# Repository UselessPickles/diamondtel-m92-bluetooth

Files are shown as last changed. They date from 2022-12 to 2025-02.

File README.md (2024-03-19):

# DiamondTel Model 92 Bluetooth Adapter



This is an electronics/microcontroller project for adapting a DiamondTel Model 92 Portable Cellular Telephone to work as a fully functional phone by routing calls through a modern cell phone via the Bluetooth Hands-Free Profile (HFP).

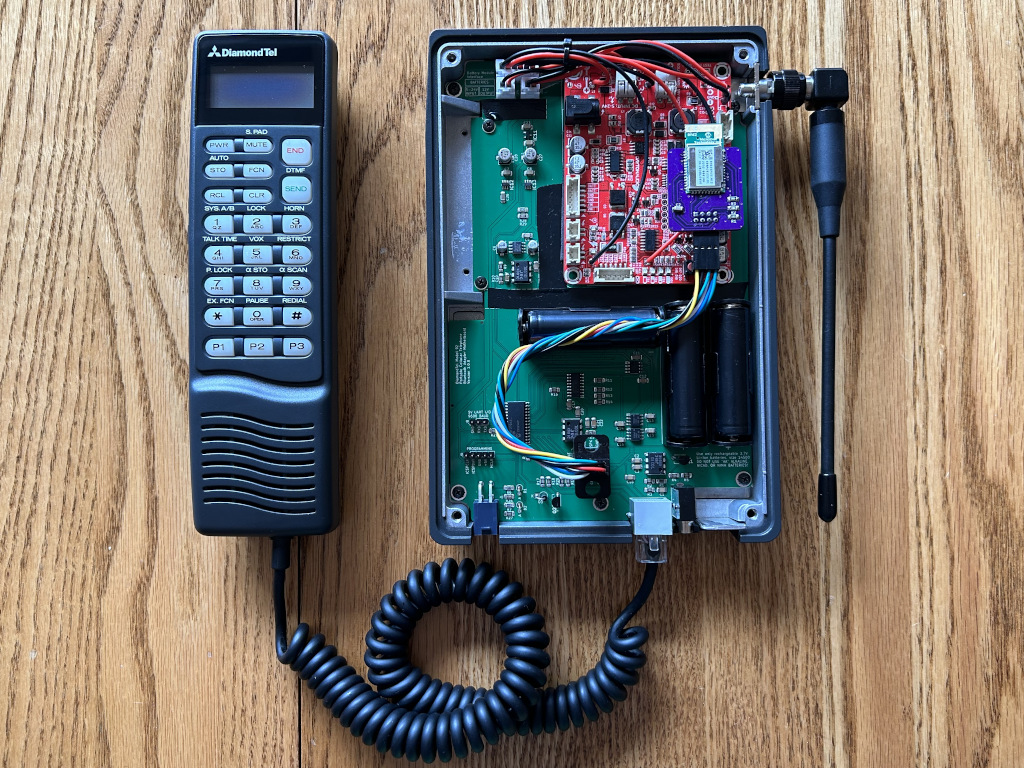
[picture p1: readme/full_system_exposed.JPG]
DiamondTel Model 92 Telephone with Bluetooth adapter electronics exposed
|

This project includes both a custom electronics circuit and custom microcontroller software.

- [DiamondTel Model 92 Bluetooth Adapter](#diamondtel-model-92-bluetooth-adapter)
  - [About This Project](#about-this-project)
    - [TL;DR (with demo videos)](#tldr-with-demo-videos)
    - [The DiamondTel Model 92 Portable Cellular Telephone](#the-diamondtel-model-92-portable-cellular-telephone)
    - [Motivation / Goals](#motivation--goals)
    - [Project Forum Thread](#project-forum-thread)
    - [Discussion](#discussion)
    - [Documentation](#documentation)
    - [Media Coverage](#media-coverage)
  - [Basic Design](#basic-design)
    - [High Level Design Summary](#high-level-design-summary)
    - [Design Pros/Cons](#design-proscons)
  - [Compatibility](#compatibility)
    - [Vintage Mobile Phone](#vintage-mobile-phone)
    - [Paired Modern Cell Phone](#paired-modern-cell-phone)
  - [About the Author](#about-the-author)  
## About This Project

### TL;DR (with demo videos)

I have an old car phone in my early 90's car. It's impossible to activate service for these old phones. I made the old car phone actually work like a real phone.

Click to view a YouTube video tour and demo of the complete car phone system with Bluetooth adapter (NOTE: This video shows an older external plug-in version):

YouTube video tour and demo of the complete car phone system with Bluetooth adapter (https://www.youtube.com/watch?v=52AuhS5Jq0Q)

Click to view a YouTube video demo and disassembly of the new internal adapter design:

YouTube video demo and disassembly of new internal adapter (https://www.youtube.com/watch?v=uEtvmijlxUE)

You can find all videos I have created about this project in [this YouTube playlist](https://www.youtube.com/playlist?list=PLOlio4FadqvQEWHDXaJHlkvHigROk-RNV).

### The DiamondTel Model 92 Portable Cellular Telephone

The DiamondTel Model 92 Portable Cellar Telephone is a hybrid transportable/mobile (mobile, as in, "car phone") manufactured by Mitsubishi in the early 1990's. 

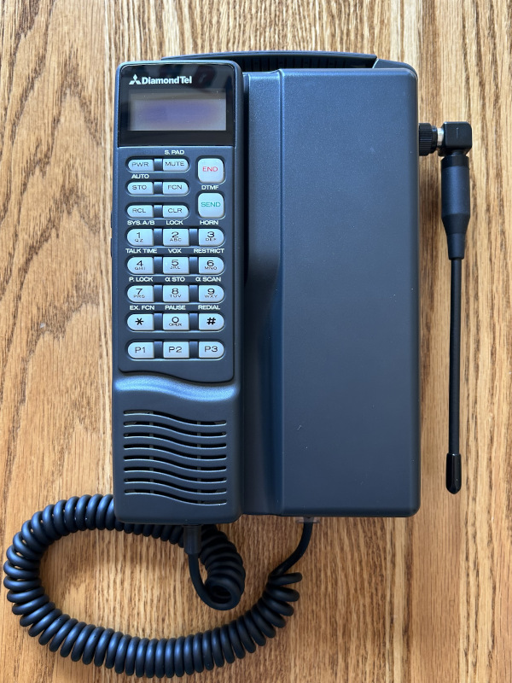
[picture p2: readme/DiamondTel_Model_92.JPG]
DiamondTel Model 92 Portable Cellular Telephone


The phone used 1G analog cellular technology ([AMPS](https://en.wikipedia.org/wiki/Advanced_Mobile_Phone_System)), which has been discontinued in the US since 2008. As such, it is impossible to activate service for this phone. 

See the contents and README in the `telephone` directory for more details.

### Motivation / Goals

I want my DiamondTel Model 92 telephone to actually work as a phone, and not just by hacking an off-the-shelf Bluetooth headset into the phone's handset. I want the complete experience of the phone to be nearly indistinguishable from how the phone was originally intended to behave:

- Incoming calls should cause the phone to ring, and I should be able to answer incoming calls as expected (press the "SEND" button or pick up the handset).
- I should be able to place outgoing calls by dialing a number on the handset then pressing "SEND".
- The handset display should work and display all relevant information just like the original phone did.
- Sounds should be accurate to the original phone (button press sounds, ringtone, status alert sounds, etc.).
- A majority of the phone's original features should be fully functional (e.g., volume controls, call timer, quick dial presets, contacts directory with names and numbers).

### Project Forum Thread

I have documented my entire journey with this project in an [Electro-Tech-Online.com forum thread](https://www.electro-tech-online.com/threads/making-a-bluetooth-adapter-for-a-car-phone-from-the-90s.162764/).

Browse this thread if you are interested in all the technical details of how I reverse-engineerd how the DiamondTel Model 92 telephone works, how I fumbled my way through the electronics/hardware (with much appreciated assistance), and various problems I had to solve.

Subscribe to this thread if you want to be notified of significant updates about this project.

### Discussion

Do you have something to ask/say about this project? You can reach out to me in [this Gitter chat room](https://gitter.im/UselessPickles/diamondtel-m92-bluetooth) or DM me on [Instagram (@uselesspickles)](https://www.instagram.com/uselesspickles/).

### Documentation

There's too much information to put in one README. Most directories of this project have a README containing relevant documentation for that portion of the project. So explore the directory structure and use the READMEs to get familiar with it.

### Media Coverage

There's been a bit of media coverage of my project. Here's some links:

- [Hackaday](https://hackaday.com/2023/04/13/custom-bluetooth-adapter-brings-1990s-car-phone-back-online/)
- [Jalopnik](https://jalopnik.com/vintage-factory-car-phone-connects-to-smartphone-1850329711)
- [CarBuzz](https://carbuzz.com/news/genius-turns-30-year-old-mitsubishi-3000gt-into-a-smartphone)
- Hagerty: Piston Slap
    - [Part 1](https://www.hagerty.com/media/advice/piston-slap/piston-slap-new-tricks-for-an-old-car-phone-part-iv/)
    - [Part 2](https://www.hagerty.com/media/advice/piston-slap/piston-slap-new-tricks-for-an-old-car-phone-part-v/)
- [Japanese Nastolgic Car](https://japanesenostalgiccar.com/mitsubishi-3000gt-car-phone-functional-with-iphone-bluetooth/)
- [Hackster.io](https://www.hackster.io/news/jeff-lau-s-open-source-bluetooth-adapter-brings-a-mitsubishi-carphone-classic-back-from-the-dead-383864868529)
- [The Drive](https://www.thedrive.com/news/clever-collector-mods-mitsubishi-3000gt-car-phone-to-work-like-an-iphone)

## Basic Design

### High Level Design Summary

This Bluetooth adapter is a complete replacement of the electronics inside the transceiver of the car phone. The handset of the car phone remains completely original and unmondified. The Bluetooth adapter pairs with a modern cell phone using the Hands-Free Profile (HFP), which enables the car phone handset to receive incoming calls and make outgoing calls through the paired modern cell phone.
    
The majority of the electronics is on the "motherboard" that installs in the metal transceiver case, and a smaller Bluetooth module "daugherboard" installs in the battery compartment of the plastic "transportable cover" so that the Bluetooth signal is not obstructed by the metal transceiver case.

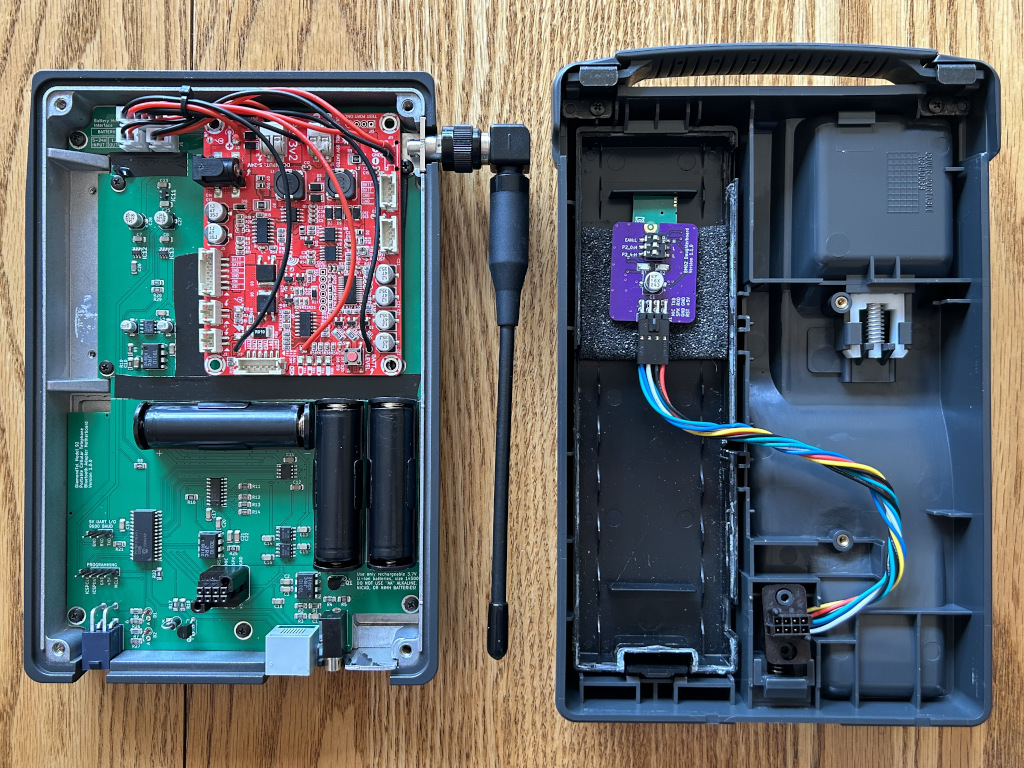
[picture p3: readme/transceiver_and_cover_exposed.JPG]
Transceiver and Transporable Cover with electronics exposed


The motherboard uses the same type of connectors as the original electronics for external power supply, handset cord, and external microphone. The connection between the mootherboard and the Bluetooth module daugherboard reuses the connectors that were originally used to connect the battery circuitry in the transportable cover to the transceiver. And finally, the Bluetooth module daughterboard can be hidden in the emptied shell of an original battery pack. The end result is that the modified car phone is practically visually indistinguishable from an original unmodified car phone, even when removing the transportable cover from the transceiver.

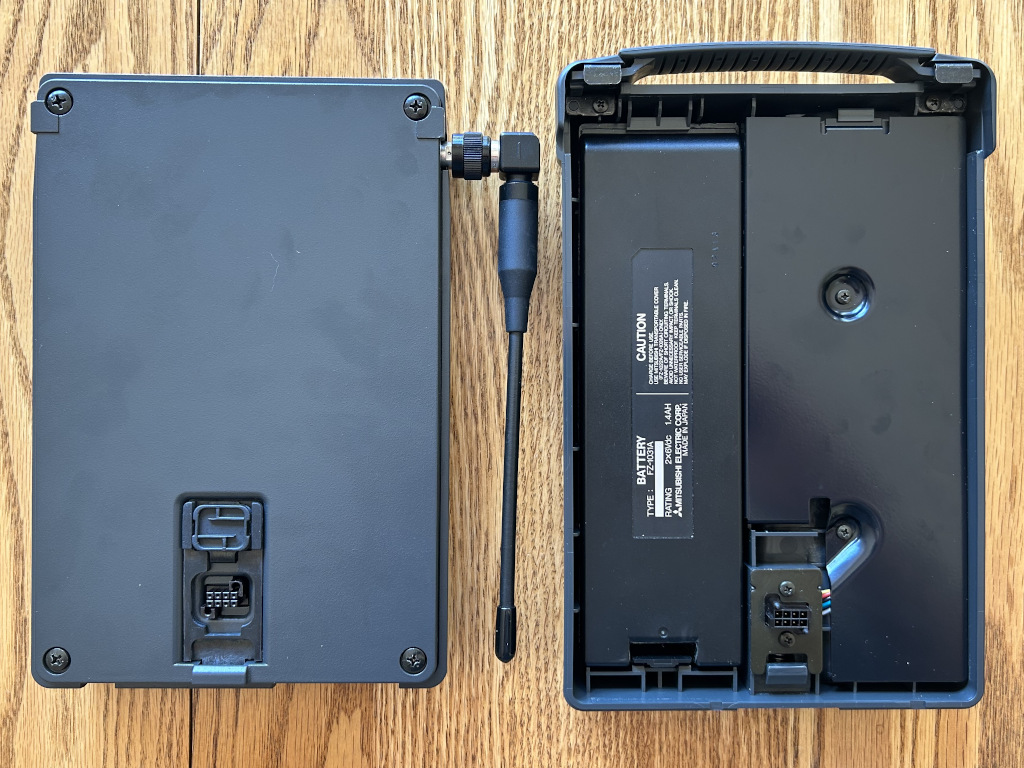
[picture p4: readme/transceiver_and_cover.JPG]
Transceiver and Transporable Cover with electronics hidden


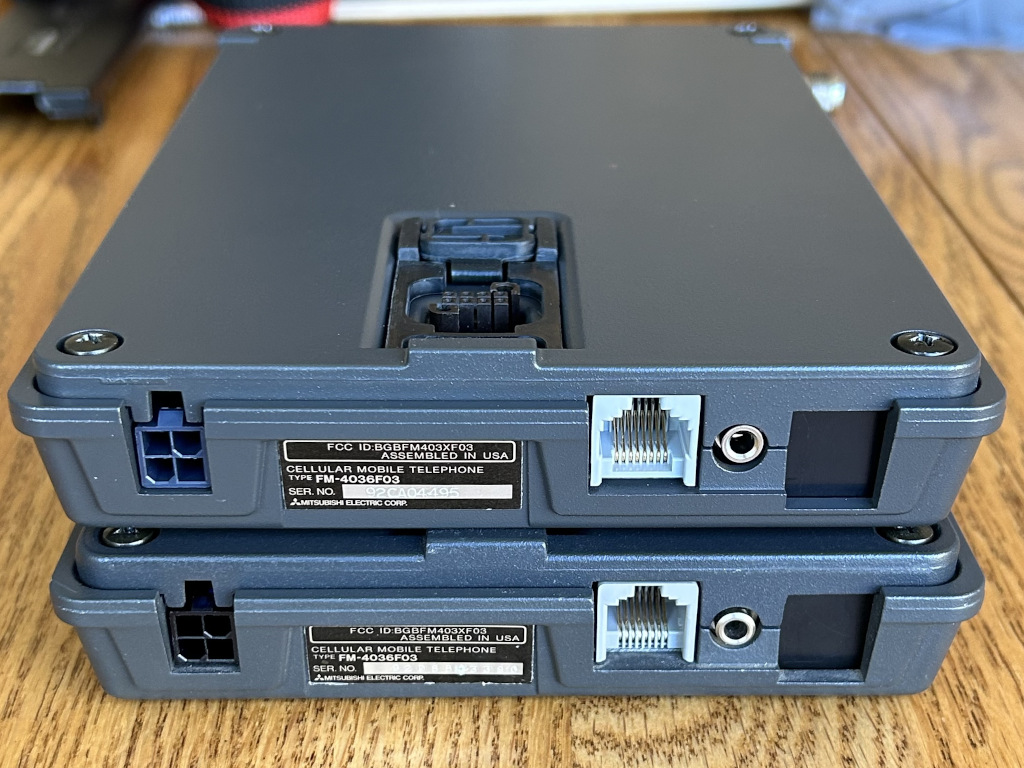
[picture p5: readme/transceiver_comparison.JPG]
Comparison of modified transceiver with unmodified transceiver

*Top: Modified transceiver; Bottom: Unmodified transceiver*

From a functionality perspective, the Bluetooth adapter faithfully replicates a large amount of the original car phone's functionality for a genuine retro experience that is often indistinguishable from the original phone. But since I do have full control of the handset, I did take the opportunity to add some new functionality (multiple ringtones, games, Caller ID, etc.). See the `operating_instructions` directory for more details.
    
### Design Pros/Cons

Pros:

- The vintage mobile phone has the appearance of being a completely original and functioning phone with no external adapters and no visible signs of modification.
- Can pair with practically any modern cell phone (no separate SIM card needed).
- I have full control of implementing any desired behavior (within limitations of the handset display/button capabilities, and within limitations of Bluetooth HFP), including functionality that was never available/possible on the original phone (e.g., Caller ID, games).

Cons:

- This is not a general design that will work with a wide range of vintage mobile phones.
- Requires a lot of custom software to replicate original DiamondTel Model 92 functionality as faithfully as possible (but that's OK with me; I'm a software engineer, and this is fun!).
- Installation is not simple, because it involves:
  - Desoldering and de-pinning some connectors from the original car pphone to transfer them to the Bluetooth adapter (these connectors are no longer available for purchase).
  - A small amount of grinding to remove some metal inside of the transceiver case.
  - Splitting open and disassembling an original battery pack if you want to hide the Bluetooth module daughterboard.

## Compatibility

### Vintage Mobile Phone

Because this design relies on a direct wired interface with the handset (using proprietary connections and digital communications), and the circuit board itself is specifically designed to fit in the transceiver case of a particular model of car phone, it has very limited compatibility. As of now, this project is only known to work with the following vintage mobile phones:

- DiamondTel Model 92
- Mitsubishi Model 1500

### Paired Modern Cell Phone

Any modern cell phone that supports Bluetooth Hands-Free Profile (HFP) _should_ (in theory) be able to pair with the Bluetooth adapter and work properly. I have a very limited selection of phones to test with, so I can't make any guarantees.

These are the modern cell phones that I have performed at least some basic testing with:

- Apple iPhone 8
- Apple iPhone SE
- Apple iPhone 14
- Google Pixel 3 XL

## About the Author

I'm a software engineer with primary professional expertise in front-end web app development, but I've also played around with some basic electronics and microcontoller programming for fun. This is by far my most ambitious electronics/microcontroller project. 

The electronics side of things is my weakness, and I've relied on quite a bit of assistance from people that know electronics better than me to get this far. If you know electronics, and think I did something stupid or unnecessary in my circuit design, then you're probably right! Please file an issue against this project if you have recommendations!

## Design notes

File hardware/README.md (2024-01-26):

# Bluetooth Adapter Hardware

This directory contains information about the hardware portion of the DiamondTel Model 92 Bluetooth adapter.

NOTE: The Bluetooth Module, Microcontroller, and Telephone all have dedicated top-level directories with relevant technical information, datasheets, and much more. This directory focuses more on combining all the components together into the bluetooth adapter hardware.

- [Bluetooth Adapter Hardware](#bluetooth-adapter-hardware)
  - [Basic Circuit Design](#basic-circuit-design)
  - [Major Circuit Components](#major-circuit-components)
    - [Microcontroller (PIC18F27Q43)](#microcontroller-pic18f27q43)
    - [Bluetooth Module (BM62)](#bluetooth-module-bm62)
    - [Hands-Free Microphone Jack (STX3120)](#hands-free-microphone-jack-stx3120)
    - [Analog Switches (MAX4619)](#analog-switches-max4619)
    - [Op Amp (NJU7031)](#op-amp-nju7031)
    - [Low-Pass Filter](#low-pass-filter)
    - [Digital Potentiometer (MCP4151)](#digital-potentiometer-mcp4151)
    - [Differential Audio Driver (INA105)](#differential-audio-driver-ina105)
    - [5V Voltage Regulator (L7805CV)](#5v-voltage-regulator-l7805cv)
    - [Negative Voltage Converter (TL7660)](#negative-voltage-converter-tl7660)
  - [Detailed Circuit Diagrams](#detailed-circuit-diagrams)
  - [Prototype Board Layout](#prototype-board-layout)
  
## Basic Circuit Design

This is a simplified component diagram of the bluetooth adapter circuit. Many details of the circuit (power, ground, voltage biasing, supporting components, etc.) are omitted for clarity of understanding the big picture of how the major components interact with each other.

[TODO]

## Major Circuit Components

This is a summary of all the major components of the bluetooth adapter circuit.

Datasheets for most components can be found in `datasheets` directory.

NOTE: Not all of these components are represented in the [Basic Circuit Design](#basic-circuit-design) diagram.

### Microcontroller (PIC18F27Q43)

This is what integrates everything together and implements all the interactive phone behavior.

See the top-level `/microcontroller` directory and the contained MPLAB project directory for more details.

### Bluetooth Module (BM62)

This handles all the Bluetooth communication with a modern cell phone, as commanded by the Microcontroller.

See the top-level `/bluetooth` directory for more details.

### Hands-Free Microphone Jack (STX3120)

This 3.5mm audio jack is used for connecting an external microphone for hands-free conversation.

The jack includes disconnect switches that are used to trigger a digital input to the MCU, indicating when
an external microphone is connected.

### Analog Switches (MAX4619)

This component is a set of 3 analog SPDT switches in one component. This is used to allow the Microcontroller to control the routing of audio:

- Choose between sending incoming voice audio or MCU-generated sounds to the Handset.
- Choose between sending the handset microphone audio or external hands-free microphone audio to the Bluetooth Module.
- Disable the microphone connection to the Bluetooth Module to temporarily "mute" the microphone while the MCU is generating sound output to the Handset.

### Op Amp (NJU7031)

This Op Amp is used to buffer the raw DAC sound output from the Microcontroller before passing it through any further circuitry.

Another is used to amplify the incoming audio from the external hands-free microphone jack.

### Low-Pass Filter

A single stage RC network is used to *partially* smooth out the 10KHz sample rate DAC audio output from the Microcontroller.

The original car phone appears to intentionally retain some high-frequency overtones in the sounds it produces. This gives the sounds a more harsh/piercing sound quality, which probably helps ensure the ringer is heard when there's an incoming call.

I similarly intentionally setup the low-pass filter to only partially smooth over the sharp corners of the DAC output. It's not an exact match to the original phone, but it sounds similar enough.

### Digital Potentiometer (MCP4151)

This digital potentiometer allows the Microcontroller to control the volume of audio output the the Handset.

### Differential Audio Driver (INA105)

A pair of INA105 precision unity gain opamps is used to produce [differential](https://en.wikipedia.org/wiki/Differential_signalling) audio output to the Handset. One is setup as unity gain, while the other is setup as inverting unity gain.

NOTE: This component requires a +5V and -5V power supply.

### 5V Voltage Regulator (L7805CV)

This voltage regulator produces a +5V power supply for the circuit. The ~12V power supply from the Transceiver is used as input.

### Negative Voltage Converter (TL7660)

This component produces a -5V power supply from the main +5V power supply. This is necessary for the [Differential Audio Driver](#differential-audio-driver-ina105).

## Detailed Circuit Diagrams

See the KiCad projects in the `kicad` directory for complete schematics and PCB layouts.

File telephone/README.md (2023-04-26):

# DiamondTel Model 92 Cellular Telephone

This directory and README contains information about the DiamondTel Model 92 Cellular Telephone that this project is designed to work with.

- [DiamondTel Model 92 Cellular Telephone](#diamondtel-model-92-cellular-telephone)
  - [About the Phone](#about-the-phone)
  - [Handset Features](#handset-features)
    - [General](#general)
    - [Display](#display)
    - [Buttons](#buttons)
    - [Backlight](#backlight)
    - [Audio](#audio)
  - [Handset Cord RJ45 Pinout](#handset-cord-rj45-pinout)
    - [Power and Ground (Pins 7 and 4)](#power-and-ground-pins-7-and-4)
    - [PWR Button (Pin 8)](#pwr-button-pin-8)
    - [Analog Audio Input (Pins 1 and 2)](#analog-audio-input-pins-1-and-2)
    - [Analog Microphone Output (Pin 3)](#analog-microphone-output-pin-3)
    - [Digital Data UART Rx/Tx (Pins 5 and 6)](#digital-data-uart-rxtx-pins-5-and-6)
  - [Handset UART Events](#handset-uart-events)
    - [Basic Button Presses](#basic-button-presses)
    - [Button Release](#button-release)
    - [CLR Button Modifier](#clr-button-modifier)
    - [Overlapping Button Presses](#overlapping-button-presses)
    - [Hook Status](#hook-status)
  - [Handset UART Commands](#handset-uart-commands)
    - [Delete Text](#delete-text)
    - [Print Text](#print-text)
    - [Text Display On/Off](#text-display-onoff)
    - [Blinking Text](#blinking-text)
    - [All Text Pixels On/Off](#all-text-pixels-onoff)
    - [Flashing Cursor](#flashing-cursor)
    - [LCD Display Angle](#lcd-display-angle)
    - [Backlight On/Off](#backlight-onoff)
    - [Indicators On/Off](#indicators-onoff)
    - [Set Signal Strength](#set-signal-strength)
    - [Audio On/Off](#audio-onoff)
    - [Request Hook Status](#request-hook-status)
    - [Mysterious UART Command and Event Response](#mysterious-uart-command-and-event-response)
  - [Handset Sound Frequencies](#handset-sound-frequencies)
  
## About the Phone

The DiamondTel Model 92 Portable Cellar Telephone is a hybrid transportable/mobile (mobile, as in, "car phone") manufactured by Mitsubishi in the early 1990's. 

DiamondTel Model 92 Portable Cellular Telephone

The phone used 1G analog cellular technology ([AMPS](https://en.wikipedia.org/wiki/Advanced_Mobile_Phone_System)), which has been discontinued in US since 2008. As such, it is impossible to activate service for this phone. 

This phone is of particular interest to me because it was available as an [official accessory from Mitsubishi for my 1993 Mitsubishi 3000GT VR4](https://www.3swiki.org/Accessory:_Cellular_Telephone). 

## Handset Features

### General

The handset is purely an I/O device, like a combined monitor, keyboard, microphone, and speakers. It only knows how to display whatever it is commanded to display, play watever sounds are provided to it, and it sends messages back to indicate when buttons are pressed/released. Whatever device the handset is plugged into (the original tranceiver, or the custom Bluetooth adapter) is responsible for actually implementing all desired behavior.

### Display

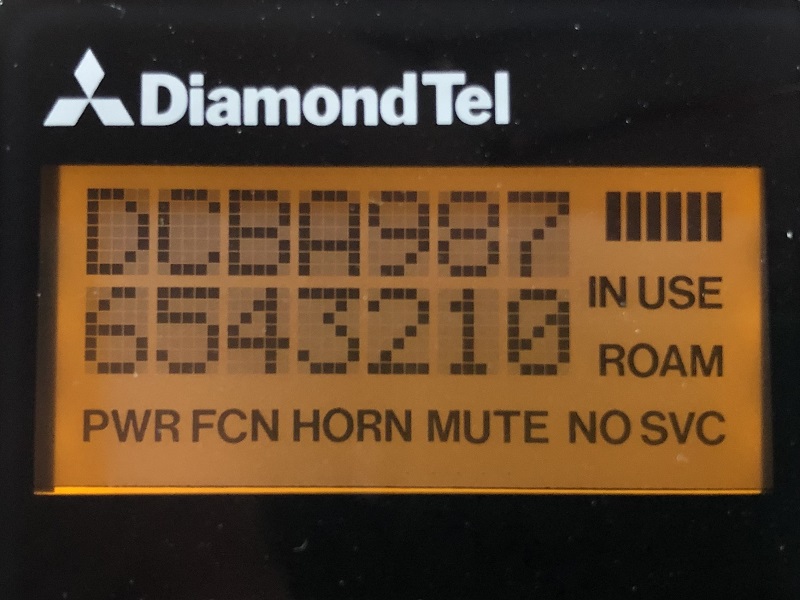
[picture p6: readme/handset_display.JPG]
Handset Display


The handset has a backlit LCD display that can display 14 characters of arbitrary text and several pre-defined status indicators.

#### Indicators

Most indicators are simply turned on/of via single UART commands. Special cases are:

- `NO SVC`: This is actually two separate indicators, `NO` and `SVC`, although they are alays turned on/off togetehr in practice.
- Signal Strength: Each of the 6 signal strength bars is an individual indicator that can be turned on/off, but there are also special UART commands for setting them to represent a numeric signal strength in the range 0-6.

See [Indicators On/Off](#indicators-onoff) and [Set Signal Strength](#set-signal-strength) for more details.

#### Text

The text portion of the display can display most standard ASCII characters, and a handful of special symbol characters that do not align with standard or extended ASCII.

There is no known way to control individual pixels, or define custom characters.

Each character position on the display can be mapped to a position index, starting with 0 at the bottom right to 6 at the bottom left, then wrapping around to 7 at the top right and continuing to 13 at the top left (the image of the display above shows this with hexadecimal index characters displayed in corresponding positions).

This order of the position indexes is also the natural flow of characters as they are "pushed" onto the display.

See [Print Text](#print-text) and [Delete Text](#delete-text) for more details.

#### Adjustable View Angle

The contrast between the "on" and "off" pixels within the text area is only ideal from a narrow viewing angle. Through some black magic I don't understand, the handset supports adjusting this ideal viewing angle (via UART commands, of course).

See [LCD Display Angle](#lcd-display-angle) for more details.

### Buttons

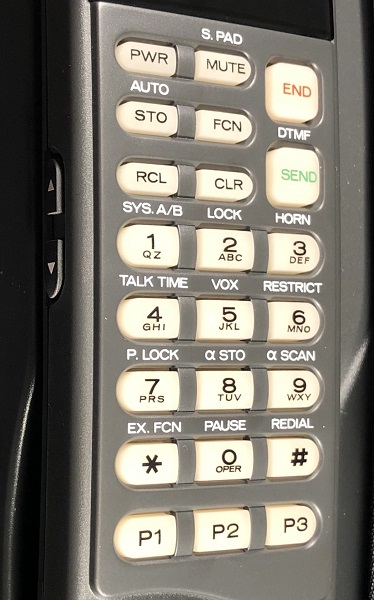
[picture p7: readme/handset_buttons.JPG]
Handset Buttons


In addition to the obvious buttons on the face of the handset, there are also 2 buttons on the side of the handset for up/down input (used for volume adjustment, scrolling through contacts, etc.). 

The [power button (PWR)](#pwr-button-pin-8) is unique in that it is the only directly-wired hardware button. All other buttons cause UART events when pressed/released.

See [Handset UART Events](#handset-uart-events) for more details.

### Backlight

Both the LCD display and the buttons on the front face of the handset have backlighting.

The backlight can be turned on/off via UART commands.

See [Backlight On/Off](#backlight-onoff) details.

### Audio

The handset has a microphone, an ear speaker, and a loud speaker.

The ear speaker and microphone are used for hand-held conversation (holding the handset up to your head). 

The loud speaker is used for hands-free conversation, as well as general sound effects (button beeps, status alerts, etc).

The phone does not have a built-in microphone for hands-free mode. Instead, the transceiver has a microphone jack for use with an external microphone.

See the RJ45 pinout sections about the [audio input](#analog-audio-input-pins-1-and-2) and [microphone output](#analog-microphone-output-pin-3) for more technical details.

Also see [Audio On/Off](#audio-onoff) for related UART commands.

## Handset Cord RJ45 Pinout

The handset cord contains 8 wires and ends with a standard RJ45 plug (same type of connector that network/ethernet cables use).

NOTE: All voltage observations mentioned in this section were taken while the handset was connected to the original telephone transceiver.

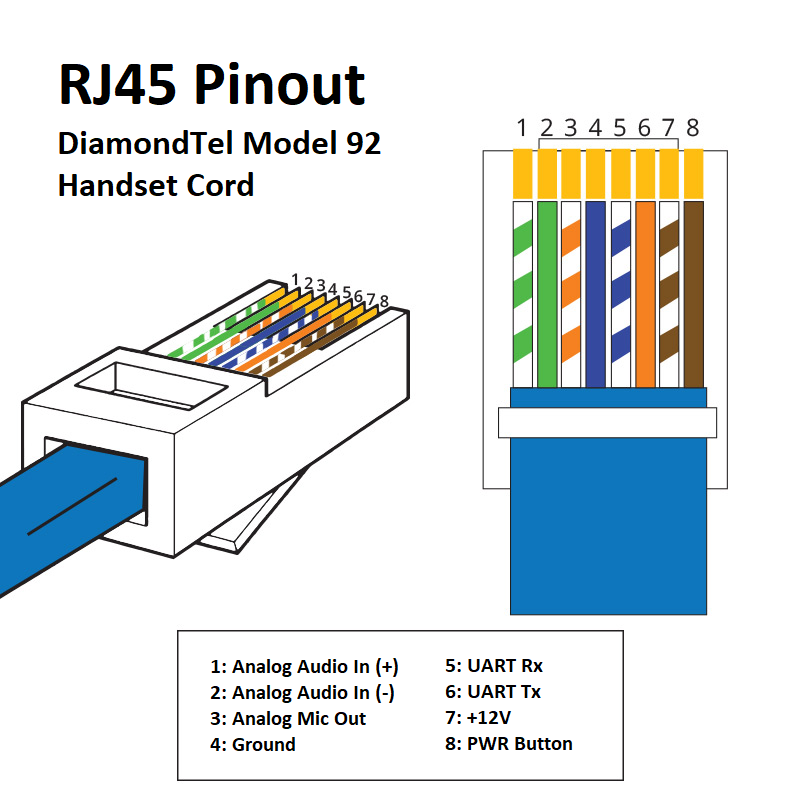
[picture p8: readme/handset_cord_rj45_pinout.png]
Handset Cord RJ45 Pinout


### Power and Ground (Pins 7 and 4)

Ground reference is provided on pin 4.

The handset turns on when about +12V is supplied to pin 7. The exact voltage varies quite a bit based on the transceiver's power supply and battery level (when battery-powered). I've casually noticed voltages in the 10-14V range.

### PWR Button (Pin 8)

Pin 8 is connected to the PWR (power) button on the handset. The button is a normally-open momentary button that connects to ground with a small resistance (~40 Ohms) when pressed. The transceiver seems to use a pull-up resister to about +12V while the phone is OFF. Voltage on this pin is just over 2V while the phone is ON (unknown why/how).

### Analog Audio Input (Pins 1 and 2)

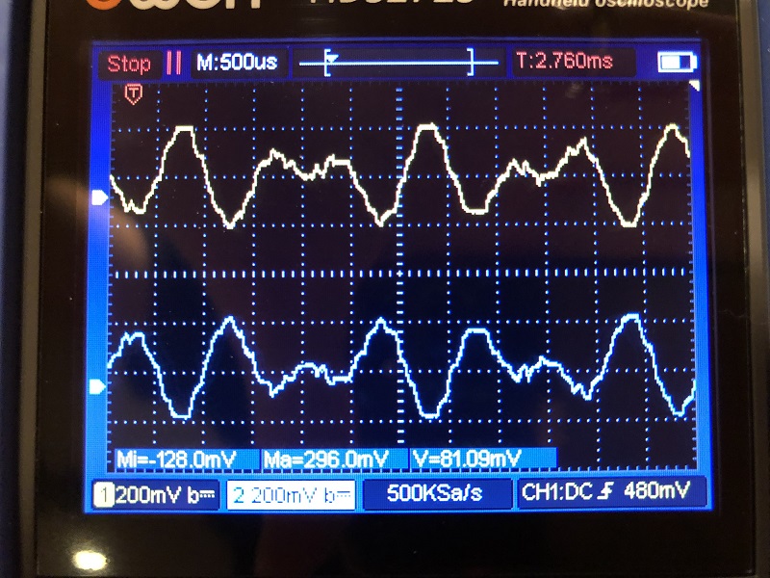
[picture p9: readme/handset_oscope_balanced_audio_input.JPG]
Oscilloscope Image of Handset Audio Input


All audio output to the handset comes in through pins 1 and 2 as analog mono-channel [differential](https://en.wikipedia.org/wiki/Differential_signalling) audio. The same audio signal is provided on both pins, but the signal on one pin is reverse polarity (negated) relative to the other pin.

The signal seems to be biased to 0V, and max peak-to-peak voltage is about 0.5V on each pin for button press sounds at the highest volume level.

NOTE 1: The audio is not played by the handset unless a speaker has been enabled by UART commands. UART commands control whether sound goes to the ear speaker or the loud speaker.

NOTE 2: The handset does not have any direct volume control. The audio source is responsible for attenuating the audio signal based on the current desired volume level.

### Analog Microphone Output (Pin 3)

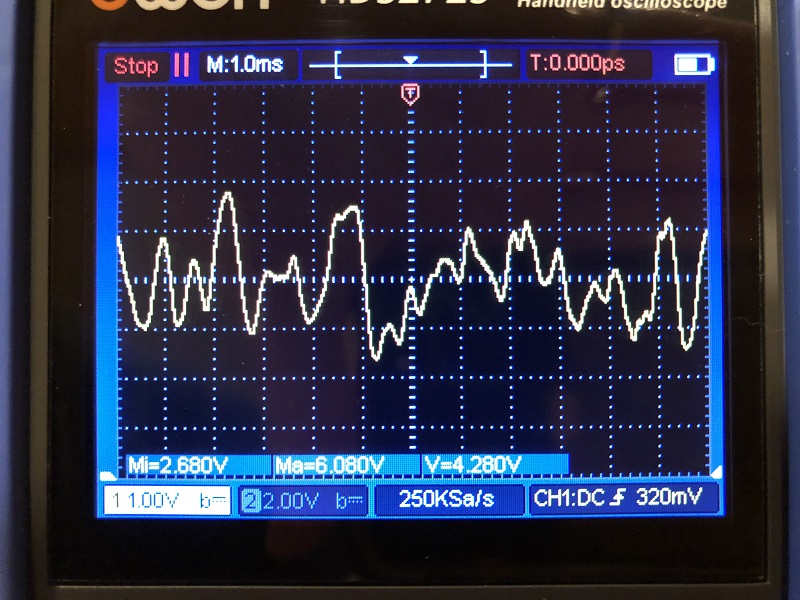
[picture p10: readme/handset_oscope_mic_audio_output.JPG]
Oscilloscope Image of Handset Microphone Audio Output


The handset outputs mono-channel microphone audio on pin 3, but only when the microphone is enabled via UART commands.

The signal seems to be biased to about 4.3V with max peak-to-peak voltage of about 5.5V.

When the microphone is disabled, voltage on this pin is about 1.7V.

### Digital Data UART Rx/Tx (Pins 5 and 6)

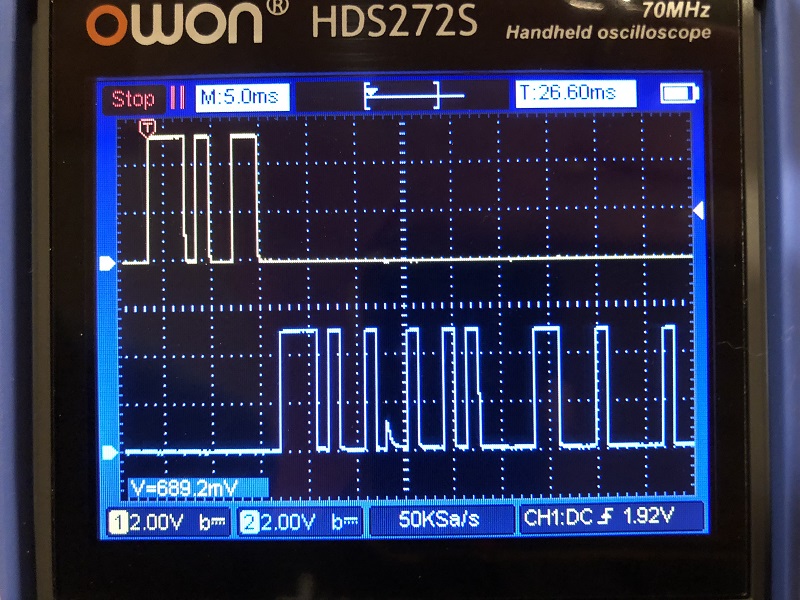
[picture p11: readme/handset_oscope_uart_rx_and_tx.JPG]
Oscilloscope Image of Handset UART Rx/Tx


The handset receives digital serial [UART](https://en.wikipedia.org/wiki/Universal_asynchronous_receiver-transmitter) messages (commands) on pin 5, and transmits digital serial UART messages (events) on pin 6.

The UART operates at 800 baud, and is inverted from standard UART (idles low, start bit is high, data bits are high=0/low=1, and stop bit is low). There are 8 data bits per message, and no parity bit.

NOTE: The operating voltage of the UART seems to fluctuate with the transceiver power supply or battery level, and can be higher than 5V.

## Handset UART Events

All UART events from the handset are simple 1-byte messages.

Also see the `DiamondTel Model 92 Handset UART Events and Commands` spreadsheet in this directory for a complete ordered list of events.

### Basic Button Presses

Aside from the [power button (PWR)](#pwr-button-pin-8), each button sends an event when pressed:

| Button | Event |
|---|---|
| # | 0x23 |
| * | 0x2A |
| 0 | 0x30 |
| 1 | 0x31 |
| 2 | 0x32 |
| 3 | 0x33 |
| 4 | 0x34 |
| 5 | 0x35 |
| 6 | 0x36 |
| 7 | 0x37 |
| 8 | 0x38 |
| 9 | 0x39 |
| [up] | 0x58 |
| [down] | 0x59 |
| CLR | 0x80 |
| FCN | 0x81 |
| P1 | 0x82 |
| P2 | 0x83 |
| P3 | 0x84 |
| STO | 0x85 |
| RCL | 0x86 |
| MUTE | 0x87 |
| END | 0x88 |
| SEND | 0x89 |

NOTE: The UART event codes for all of the "printable" buttons (#, *, and all numbers) are also the ASCII code for the same character on the buttons.

### Button Release

There is only a single UART event code sent when any button is released. There is no way to deduce from the event code itself which button was released.

| Action  | Event |
|---|---|
| Release | 0x04  |

NOTE: The event code for button release is also the ASCII `EOT` code.

### CLR Button Modifier

If the `CLR` button is held down while pressing another button, then the handset sends a distinct event code to indicate that the button was pressed with the `CLR` button also held down:

| Button | Event |
|---|---|
| CLR + 0 | 0x90 |
| CLR + 1 | 0x91 |
| CLR + 2 | 0x92 |
| CLR + 3 | 0x93 |
| CLR + 4 | 0x94 |
| CLR + 5 | 0x95 |
| CLR + 6 | 0x96 |
| CLR + 7 | 0x97 |
| CLR + 8 | 0x98 |
| CLR + 9 | 0x99 |
| CLR + # | 0x9A |
| CLR + * | 0x9B |
| CLR + P1 | 0x9C |
| CLR + P2 | 0x9D |
| CLR + P3 | 0x9E |
| CLR + STO | 0x9F |
| CLR + RCL | 0xA0 |
| CLR + MUTE | 0xA1 |
| CLR + END | 0xA2 |
| CLR + SEND | 0xA3 |
| CLR + [up] | 0xA4 |
| CLR + [down] | 0xA5 |

There are two notable exceptions:
- `CLR` - Because you obviously can't press `CLR` while `CLR` is already held.
- `FCN` - The `FCN` always sends the plain event for `FCN` regardless of whether the `CLR` button is held.

The purpose for these special event codes in the original phone behavior was to support special `CLR`-codes to enter special diagnostic and programming modes. Entering these modes requires that you power on the phone, then within 10 seconds, press and hold `CLR` while typing a sequence of numbers.

NOTE: Only this special event code is sent when a button is pressed while the `CLR` button is held. The regular event code for the button press is not sent in this situation.

### Overlapping Button Presses

There's some very interesting behavior when multiple button presses overlap each other. Combined with the limitation of only a single "button release" event code, this can unfortunately make it impossible to accurately keep track of which buttons are truly pressed at any given time.

For all buttons except `FCN` and `CLR`, the handset cannot keep track of more than one button at a time. Some examples of button press sequences and resulting events are the best way to explain this.

| # | Action | Event |
|---|---|---|
| 1 | Press 1 | 0x31: Press 1 |
| 2 | Press 2 | 0x04: Release |
| 3 | Release 1 | 0x32: Press 2 |
| 4 | Release 2 | 0x04: Release |

The above example shows that rushed 2-finger/thumb typing of number sequences still produces overall correct results, but changing the order in which the 2 buttons are released will produce the following strange results:

| # | Action | Event |
|---|---|---|
| 1 | Press 1 | 0x31: Press 1 |
| 2 | Press 2 | 0x04: Release |
| 3 | Release 2 | 0x31: Press 1 |
| 4 | Release 1 | 0x04: Release |

When `FCN` or `CLR` are involved, then the sequence of events makes more sense, but there's still ambiguity in the release events. The same exact sequence of events occurs regardless of the order in which the 2 buttons are released.

| # | Action | Event |
|---|---|---|
| 1 | Press FCN | 0x81: Press FCN |
| 2 | Press 1 | 0x31: Press 1 |
| 3 | Release 1 | 0x04: Release |
| 4 | Release FCN | 0x04: Release |

| # | Action | Event |
|---|---|---|
| 1 | Press CLR | 0x80: Press CLR |
| 2 | Press 1 | 0x91: Press CLR + 1 |
| 4 | Release CLR | 0x04: Release |
| 3 | Release 1 | 0x04: Release |

As a result of these confusing event sequences, it's best to avoid any UX design that relies on multiple overlapping button presses, except for handling the special `CLR`-modified button presses.

### Hook Status

Whenever the handset is picked up ("off hook") or hung back up ("on hook"), it sends an event to report the change in hook status.

| Hook Status | Event |
|---|---|
| On Hook | 0x8A  |
| Off Hook | 0x8B  |

NOTE: There is also a UART command to [request the hook status](#request-hook-status) at any time.

## Handset UART Commands

All UART commands are simple 1-byte messages, except for the 2-byte message sequence used for [Positioned Printing](#positioned-printing).

Also see the `DiamondTel Model 92 Handset UART Events and Commands` spreadsheet in this directory for a complete ordered list of commands.

### Delete Text

The single command deletes all text from the display.

| Action | Command |
|---|---|
| Delete All Text | 0x7F |

NOTE: this command code is the same as the ASCII delete character.

### Print Text

There are two ways to print text to the display:
1. "Standard" printing.
1. "Positioned" printing.

#### Standard Printing

"Standard" printing is as simple as sending the UART command code that corresponds to the character you want to print to the display. The character will be printed to position 0 of the text display, and all prevously printed characters will be pushed up to the next higher position (See the [Text Display](#text) section for display positioning info).

| Command | Printed Character Description |
|---|---|
| 0x20 - 0x7E | Standard ASCII characters (with a few exceptions below) |
| 0x5C | `¥` (yen symbol; deviates from standard ASCII for `\`) |
| 0x60 | `α` (greek alpha; deviates from standard ASCII for backtick) |
| 0x7E | `→` (right arrow; deviates from standard ASCII for `~`) |
| 0xC0 | Small up arrow (outline) |
| 0xC1 | Small down arrow (outline) |
| 0xC2 | Small up arrow (solid) |
| 0xC3 | Small down arrow (solid) |
| 0xC4 | Large up arrow (solid) |
| 0xC5 | Large down arrow (solid) |
| 0xC6 | Solid rectangle (all pixles of the character) |
| 0xC7 | Horizontally striped rectangle, or upside-down "T" symbol, depending on age of handset |

#### Positioned Printing

A character can be printed to a specific display position using the positioning commands (See the [Text Display](#text) section for display positioning info).

| Action | Command |
|---|---|
| Set next print position | 0x01 - 0x0E |

The command for a desired display position is calculated as `0x01 + [display position index]`, where `[display position index]` is in the range `0 - 13`.

After sending the positioning command, send a [standard character printing command](#standard-printing), and the specified character will be printed to the desired position.

NOTE: The positioning command only affects the immediately next character printing command. A subsequent character printing command would print via [Standard Printing](#standard-printing).

#### Interaction between Standard and Positioned Printing

If a position print places a character in a position currently occupied by a standard printed character, then the positioned character overwrites the character at that position, but retains the behavior of standard printing. It will be pushed to the next higher position next time standard printing pushes a character onto the display.

However, if a positioned print places a character in a position that has NOT yet been reached by standard printing, then the positioned character will remain in its initial position until standard printing "overtakes" and overwrites it.

### Text Display On/Off

The text portion of the display can be turned on/off.

While the text display is OFF, no text is displayed, but the handset still maintains state of what is currently printed.

| Action | Command |
|---|---|
| Text Display ON  | 0xB6 |
| Text Display OFF | 0xB7 |

The normal use case for this feature is to disable the text display before printing multiple characters, then re-enable the text display after all characters are printed. The UART baud rate is so slow that the progress of printing an entire string of characters is visible to the user if the display is not disabled while printing.

### Blinking Text

The handset supports a blinking text mode, where the entire text display flashes on/off at about 1 flash per second.

| Action | Command |
|---|---|
| Blinking ON | 0xB8 |
| Blink OFF | 0xB9 |

NOTE: This blinking effect is acheived by automatically enabling/disabling the text display. Any attempt to manually [enable/disable the text display](#text-display-onoff) will quickly be overridden by the blinking, until the blinking is disabled.

### All Text Pixels On/Off

There are commands for turning all text display pixels on/off.

| Action | Command |
|---|---|
| All Pixels ON  | 0xBA |
| All Pixels OFF | 0xBB |

The interaction between this and the current state of characters printed to the display is unknown. It is recommended to use the [delete command](#delete-text) to clear the text display instead, because the original transceiver was observed to always use the delete command for clearing the display.

### Flashing Cursor

A flashing cursor can be placed at any text display position (See the [Text Display](#text) section for display positioning info). The cursor alternates between a solid rectangle and whatever character is currently printed to the same position.

| Action | Command |
|---|---|
| Display Cursor | 0xD0 - 0xDD |
| Hide Cursor | 0xDE |

The command for displaying the cursor at a desired position is calculated as `0xD0 + [display position index]`, where `[display position index]` is in the range `0 - 13`.

The cursor can only be displayed while the text display is enabled. The cursor will be automatically hidden if the [text display is disabled](#text-display-onoff), or if [text is deleted](#delete-text).

There are unfortunately some strange bugs with the flashing cursor:
1. After the  flashing cursor position is set higher than 6, positioning seems to become corrupted until a character is printed to the display.
1. Cursor cannot be displayed at positions 0-6 unless at least one character has been already printed to the display.
1. Hiding the cursor doesn't always seem to work.

Through trial and error, the following sequence has been found to reliably position and reposition the cursor anywhere on the display:
1. Print any character anywhere on the display.
1. Send the `Hide Cursor` command (`0xDE`).
1. Send the desired `Show Cursor` command (`0xD0 - 0xDD`).

Conveniently, the `Hide Cursor` command always seems to work after using the above sequence to display the cursor.

NOTE: It's fairly easy to keep track of what character is currently printed at display position `0` at all times (defaulting to a blank space if nothing is printed). This character can then be printed at position 0 to achieve the first step of the above sequence without altering the current text on the display.

### LCD Display Angle

The [adjustable view angle](#adjustable-view-angle) of the LCD text display can be set to one of 8 settings.

| Action | Command |
|---|---|
| Set Viewing Angle | 0xC8 - 0xCF |

The command for setting the desired view angle is calculated as `0xC8 + [view angle]`, where `[view angle]` is in the range `0 - 7`.

NOTE: The view angles presented on screen to the user by the original phone are in reverse order, and one-based. That is, `[displayed angle] = 8 - [view angle]` and `[view angle] = 8 - [displayed angle]`, where `[displayed angle]` is in the range `1 - 8`.

### Backlight On/Off

The handset's [backlight](#backlight) can be turned on/off.

| Action | Command |
|---|---|
| Backlight ON  | 0xAC |
| Backlight OFF | 0xAD |

### Indicators On/Off

Every [status indicator](#indicators) on the display can be toggled on/off with a pair of commands per indicator. There is also a pair of commands that turns ALL indicators on/off.

| Indicator | ON Command | OFF Command |
|---|---|---|
| PWR | 0x82 | 0x83 |
| FCN | 0x84 | 0x85 |
| HORN | 0x86 | 0x87 |
| MUTE | 0x88 | 0x89 |
| IN USE | 0x9C | 0x9D |
| ROAM | 0x80 | 0x81 |
| NO | 0x8A | 0x8B |
| SVC | 0x8E | 0x8F |
| Signal Bar #1  | 0x90 | 0x91 |
| Signal Bar #2  | 0x92 | 0x93 |
| Signal Bar #3  | 0x94 | 0x95 |
| Signal Bar #4  | 0x96 | 0x97 |
| Signal Bar #5  | 0x98 | 0x99 |
| Signal Bar #6  | 0x9A | 0x9B |
| All Indicators | 0xBC | 0xBD |

NOTE: There's a common pattern of `[off command] = [on command] + 1` for each pair of on/off commands.

### Set Signal Strength

The signal strength [indicator](#indicators) bars can be updated conveniently with a single command to turn each individual signal bar on/off as needed to represent a specified numeric signal strength.

| Action | Command |
|---|---|
| Set Signal Strength | 0xE0 - 0xE6 |

The command to set the desired signal strength is calculated as `0xE0 + [signal strength]`, where `[signal strength]` is in the range `0 - 6`.

### Audio On/Off

Each of the [audio components](#audio) of the handset (ear speaker, loud speaker, microphone) can be turned on/off. There are also commands for "master audio" (the entire audio circuit of all audio components).

| Audio Component | ON Command | OFF Command |
|---|---|---|
| Master | 0xB4 | 0xB5 |
| Microphone | 0xBE | 0xBF |
| Loud Speaker | 0xEB | 0xEC |
| Ear Speaker | 0xED | 0xEE |

NOTE: There's a common pattern of `[off command] = [on command] + 1` for each pair of on/off commands.

In order for an audio component to be fully ON, the "Master" audio must also be ON.

The on/off state of individual components is retained and can be changed while Master audio is off.

Turning master audio off likely conserves power better than simply turning the individual components off, but be aware that it takes longer for the Master audio to turn on/off (which can cause a delay in producing sound), and it can cause a "pop" in the audio.

### Request Hook Status

The current hook status of the handset can be requested at any time, and the handset will respond immediately with the [event for its current hook status](#hook-status).

| Action | Command | Response Event |
|---|---|---|
| Request Hook Status | 0xDF | [Hook Status](#hook-status) |

### Mysterious UART Command and Event Response

There is a command that causes the handset to respond immediately with a mysterious event. The meaning of this command and event is unknown.

| Meaning | Command | Response Event |
|---|---|---|
| Mystery | 0xEA | 0x8C |

I have tested with multiple handsets, and all respond with the same value.

## Handset Sound Frequencies

In addition to [standard DTMF tones](https://en.wikipedia.org/wiki/Dual-tone_multi-frequency_signaling), the various beeps and tones produced by the original phone are made up of two frquencies:

| Tone Type | Frequency |
|---|---|
| Low | 768 Hz |
| High | 1152 Hz |

NOTE: The Low tone is close enough to one of the standard DTMF frequencies (770 Hz) that it is probably safe to assume that it was intended to be the same.

There are several different kinds of sounds the phone makes with these 2 tones:

| Sound Type | Low | High | Notes |
|---|-----|---|---|
| Tone | X | X | When adjusting "Tone" volume |
| Power On | X | X | |
| Button Beep | X | | Except for DTMF tones in certain situations |
| Power Off | | X | |
| Status Indicator| | X | (If enabled) Beeps when service status changes (NO SVC, ROAM)|
| Alert (Ringer)  | X | X | Alternates evenly between both tones on simultaneously, and silence, repeating at 20 Hz |
| Low Battery | | X | Beeps for 1 second, every 20 seconds, while battery level is low. |
| Call Failed | X | X | Alternates between high and low, repeating at 1 Hz |

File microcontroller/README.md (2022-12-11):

# PIC18F27Q43 Microcontroller 

This directory contains information and software for the Microchip PIC18F27Q43 microcontroller.

The microcontroller software implements the majority of the functionality of this project:

- Interfaces with the DiamondTel Model 92 handset for user I/O.
- Interfaces with the DiamondTel Model 92 transceiver to monitor the battery level.
- Interfaces with the BM62 Bluetooth Module to pair with a modern cell phone as a "Hands Free" device, sending/receiving calls, etc.
- Interfaces with a digital potentiometer and digital switch IC to manage sound volume and routing.
- Implements all the behavior that makes the phone act like a phone.

## Software Source Code

The `DiamondTelM92Bluetooth.X` directory is a complete [MPLAB X](https://www.microchip.com/en-us/tools-resources/develop/mplab-x-ide) project containing all source code and configuration for the PIC18F27Q43 software.

See the README in that directory for more details on the project organization.

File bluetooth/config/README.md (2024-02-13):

# BM62 Bluetooth Module Configuration

This directory contains configuration files for the Microchip BM62 Bluetooth Module for use in this project.

- [BM62 Bluetooth Module Configuration](#bm62-bluetooth-module-configuration)
  - [Contents](#contents)
  - [Configuration Summary](#configuration-summary)
  - [Tools](#tools)
  - [Prepare the BM62 for Firmware/Configuration Install](#prepare-the-bm62-for-firmwareconfiguration-install)
  - [Firmware Install](#firmware-install)
  - [Configuration Install](#configuration-install)

## Contents

- `firmware`: BM62 firmware version 2.1.5 hex file.
- `src`: The individual sources for the custom configuration.
    - The two `.txt` files are the source config files that can be edited with the `UI Tool` and the `DSP Tool`.
    - The `IS206X_012_DUALMODESPK2.1_E1.0.4.1_1214.bin` is the "default BIN" file that is combined together with the `UI` and `DSP` config source files using the `MPET` tool to produce the "UI Patch" found in the `dist` directory.
- `dist`: The EEPROM "UI Patch" files containing the custom configuration for this project, ready to be installed onto the BM62.

## Configuration Summary

The BM62 configuration for this project is very simple and limited compared to what the BM62 is capable of:

- UART communication enabled at 115200 baud.
- HFP profile only (no audio streaming for music, etc.).
- "Power on directly" (no power button or UART power on/off support).
- No battery charging.
- No user interaction through buttons (all interactions will be done by the MCU via UART commands).
- No automatic linkback when powering on, automatic retries, timeouts, etc. (all linkback/pairing behavior is managed by the MCU via UART commands).

## Tools

Download the `BM64 DSPK 2.1.5` software/tools from [Microchip's product page for the BM62](https://www.microchip.com/en-us/product/BM62).

BEWARE: Various documentation, instructions, readme files, etc., from Microchip have incorrect information about updating firmware and configuration on the BM62. Follow the instructions in this README.

In addition to the software tools provided by Microchip, you will also need a USB to UART adapter to install the
firmware and configuration onto the BM62 module. I found the `DSD TECH SH-U09C5` to be a very good option (reputable chipset, supports more baud rates than some other options, adjustable voltage).

## Prepare the BM62 for Firmware/Configuration Install

It's easiest to install firmware/configuration on the BM62 if it is completely separable from the rest of the hardware. When developing on a breadboard, this is as easy as temporarily removing some strategic connections on the board. If you're working with a soldered prototype/perf board, it's probably a good idea to use a breadboard adapter and female headers soldered to the perf board so that the BM62 can be transferred to a breadboard for updates. Otherwise, the circuit design will require more complexity to support in-circuit updates.

The following setup is needed for both Firmware and Configuration installation:
- 22uF cap between `VDD_IO` and ground.
    - See Errata document for more info.
- `RXD`, `TXD`, Power, ground, and `#RESET` disconnected from the rest of the circuit so that the MCU cannot interfere with the update and no pins are inadvertently pulled low.
- Connect a USB-UART adapter to the BM62.
    - Ground to ground.
    - +5V to `ADAPTER_IN`
    - `TXD` to `RXD`
    - `RXD` to `TXD`

## Firmware Install

This section will guide you through installing the correct version of the core firmware for the BM62. The BM62 very likely comes pre-installed with an older firmware version.

NOTE: If you have previously installed the DSPK 2.1.5 firmware and only need to install a new version of the configuration for this project, then skip to the [Configuration Install](#configuration-install) section.

Consider reviewing the following resources that guided the writing of the following instructions (these were both sent to me by Microchip tech support when asking how to install firmware 2.1.5 on a BM62):
- [A Microchip Knowledge Base article about installing firmware 2.1.5 on a BM64](https://microchipsupport.force.com/s/article/BM64-Firmware-update-for-DSPK-v2-1-5-package).
- [A YouTube video about installing firmware 2.1.5 on a BM62](https://www.youtube.com/watch?v=s2zi_sSPKU0).

Installation instructions:
1. [Prepare the BM62 for Firmware/Configuration Install](#prepare-the-bm62-for-firmwareconfiguration-install)
1. Make the following connections on the BM62 (NOTE: Do this BEFORE connecting power to the BM62, or reset the BM62 after):
    - `EAN` pulled high to `VDD_IO` 
        - NOTE: Datasheet incorrectly claims EAN has an internal pull-up resistor.
    - `P2_0` pulled low.
1. Launch the `DSPK v2.1.5 Package\Tools\FlashUpdate Tool\isupdate.exe` tool.
    - The readme file for these tools says that `isupdate` should not be used for BM62, but there is no way to install firmware version 2.1.5 using the specified `isbtflash` tool for the BM62. I got these instructions from Microchip tech support as a "workaround".
1. Select the following options:
    - `port`: The port that your USB-UART adapter maps to.
    - `baudrate`: 115200
    - `image num`: 1
    - `Memory Type / type`: flash
    - `Memory Type / subtype`: Serial Flash
1. Click `Connect`.
1. Click the first `Browse` button in the `Flash Update/Dump` section and choose the `firmware/BT5506_SHS_FLASH_Rehex_0F95_Rehex_0F3A.HEX` file from here in this project.
1. Click the `Update` button next to the `Browse` button you used.
1. Click `Disconnect` when done.

## Configuration Install

This section will guide you through installing the customized configuration of the BM62 for use in this DiamondTel Model 92 Bluetooth Adapter project.

NOTE: The [correct firmware must already be installed](#firmware-install) on the BM62 before proceeding.

Installation instructions:
1. [Prepare the BM62 for Firmware/Configuration Install](#prepare-the-bm62-for-firmwareconfiguration-install)
1. Make the following connections on the BM62 (NOTE: Do this BEFORE connecting power to the BM62, or reset the BM62 after):
    - `P2_0` pulled low.
1. Launch the `DSPK v2.1.5 Package\Tools\EEPROM_Tool\EEPROM_Tool.exe` tool.
1. Select the port that your USB-UART adapter maps to.
1. Click `IC/Module Identify` to verify the connection to the BM62.
1. Click the `...` button in the `WRITE EEPROM` section and choose the `dist/DiamondTelM92Bluetooth.ipf` file from here in this project.
1. Click the `Write` button.

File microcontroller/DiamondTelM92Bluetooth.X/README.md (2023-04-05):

# PIC18F27Q43 Microcontroller Software Project

This directory is a complete [MPLAB X](https://www.microchip.com/en-us/tools-resources/develop/mplab-x-ide) project containing all source code and configuration for the PIC18F27Q43 microcontroller software.

- [PIC18F27Q43 Microcontroller Software Project](#pic18f27q43-microcontroller-software-project)
  - [General](#general)
    - [Sloppy Prototype Under Construction](#sloppy-prototype-under-construction)
    - [MPLAB Code Configurator](#mplab-code-configurator)
    - [Adapted from Microchip's BM62 Demo Software](#adapted-from-microchips-bm62-demo-software)
  - [Peripherals and I/O Pins](#peripherals-and-io-pins)
    - [TMR0 - Call Timer](#tmr0---call-timer)
    - [TMR2 - General Purpose 10ms Timer](#tmr2---general-purpose-10ms-timer)
    - [TMR4 - General Purpose 1ms Timer](#tmr4---general-purpose-1ms-timer)
    - [TMR6 - Sound Sample Output Timer](#tmr6---sound-sample-output-timer)
    - [FVR - Fixed Voltage Reference](#fvr---fixed-voltage-reference)
    - [DAC1 - Sound Sample Output Value](#dac1---sound-sample-output-value)
    - [SPI1, RC3 (SPI1_CS_DPOT) - Volume Control Communication](#spi1-rc3-spi1_cs_dpot---volume-control-communication)
    - [RA6 (IO_VOICE_IN) - Incoming Voice Audio Switching](#ra6-io_voice_in---incoming-voice-audio-switching)
    - [RA5 (IO_MIC_OUT_DISABLE) - Microphone Audio Disable](#ra5-io_mic_out_disable---microphone-audio-disable)
    - [RA7 (IO_MIC_HF_SELECT) - Microphone Audio Switching](#ra7-io_mic_hf_select---microphone-audio-switching)
    - [RA3 (IO_MIC_HF_DETECT) - External Hands-Free Microphone Detection](#ra3-io_mic_hf_detect---external-hands-free-microphone-detection)
    - [UART3 - Handset Communication](#uart3---handset-communication)
    - [UART2 - Bluetooth Module Communication](#uart2---bluetooth-module-communication)
    - [UART1 - STDIO Logging/Debugging](#uart1---stdio-loggingdebugging)
    - [UART4 - Transceiver Communication](#uart4---transceiver-communication)
    - [RC4 (IO_BT_RESET) - Bluetooth Module Reset](#rc4-io_bt_reset---bluetooth-module-reset)
    - [RC5 (IO_BT_MFB) - Bluetooth Module UART Rx Indicator](#rc5-io_bt_mfb---bluetooth-module-uart-rx-indicator)
    - [RB5 (IO_PWR) - Handset Power Button](#rb5-io_pwr---handset-power-button)
    
## General 

### Sloppy Prototype Under Construction

Much of the code is not up to my personal standards, so don't judge me too harshly. This project is still in the transition phase from a quick, sloppy, and incrementally updated proof-of-concept to a more deliberately designed and implemented solution.

In particular, the bulk of the phone functionality in `app.c` is a big confusing mess that needs to be split out separate more manageable files, and the sound engine in `sound.c` is in need of a redesign. Many of the other files still require cleanup and documentation.

### MPLAB Code Configurator

This project uses the MPLAB Code Configurator to generate code for most of the initialization/configuration of various peripherals, pin assignments, etc. 

The `mcc_generated_files` directory contains the generated output of the Code Configurator. Use the Code Configurator to make changes to the peripheral/pin configurations rather than updating these files directly.

NOTE: Some generated files have minor customizations that will need to be preserved if new files are generated.

### Adapted from Microchip's BM62 Demo Software

The demo evaluation board software from Microchip's `BM64 DSPK v2.1.3` software/tools package was used as a starting point for implementing UART communications with the BM62 Bluetooth Module. The `bt_command_send` and `bt_command_decode` source files started as an exact copy/paste from the demo project, then modified/simplified as needed. Otherwise, all other (non-generated) source code in this project is original code for this project.

## Peripherals and I/O Pins

This is a summary of what each peripheral and I/O pin is used for.

### TMR0 - Call Timer

This timer is used exclusively for counting seconds during a call to maintain the call timer (see `call_timer.c`). The timer is only running during a call. 

Because this timer is dedicated to this one purpose, and is started at the beginning of a call, it produces good accuracy of elapsed call time.

### TMR2 - General Purpose 10ms Timer

This timer is setup to trigger every 10ms and is always running. It is used for general purpose low-precision timing of timeouts/intervals throughout the project.

Because this timer is always running, and timing of timeouts/intervals is done in terms of timer interupt counts, be aware that actual amount of between starting a timeout/interval and when it ends/triggers can be short by up to 10ms (e.g., the first "count" can happen nearly immediately if the timer event was already about to trigger).

### TMR4 - General Purpose 1ms Timer

This timer is setup to trigger every 1ms and is always running. It is used for general purpose higher-precision timing of timeouts/intervals throughout the project.

Because this timer is always running, and timing of timeouts/intervals is done in terms of timer interupt counts, be aware that actual amount of between starting a timeout/interval and when it ends/triggers can be short by up to 1ms (e.g., the first "count" can happen nearly immediately if the timer event was already about to trigger).

### TMR6 - Sound Sample Output Timer

This timer is used exclusively for generating sound output (see `tone.c`). It is setup to trigger every 100us, for a sample rate of 10kHz. It is used together with [DAC1](#dac1---sound-sample-output-value) to output the sound samples.

This timer's interrupt is the only high-priority interrupt, to guarantee consistency of the sound output sample rate. 

### FVR - Fixed Voltage Reference

The FVR is setup to provide a 1.024V reference to [DAC1](#dac1---sound-sample-output-value). This conveniently limits the analog sound output to a level that produces the maximum desired audio volume level, and keeps the signal well within the full-swing range of the Op Amp that buffers the signal.

### DAC1 - Sound Sample Output Value

This is used together with [TMR6](#tmr6---sound-sample-output-timer) and [FVR](#fvr---fixed-voltage-reference) to output sound samples (see `tone.c`).

### SPI1, RC3 (SPI1_CS_DPOT) - Volume Control Communication

This is used to communicate with a digital potentiometer via SPI for sound volume control (see `volume.c`). The `RC0` pin is a digital output used for the Chip Select (CS) line.

### RA6 (IO_VOICE_IN) - Incoming Voice Audio Switching

This digital output pin is used to control an analog switch that chooses whether to use incoming voice audio from the Bluetooth Module, or generated sounds from the MCU, as the source of sound to be provided to the phone handset.

### RA5 (IO_MIC_OUT_DISABLE) - Microphone Audio Disable

This digital output pin is used to control an analog switch that disconnects the handset microphone output from the Bluetooth module. This is used to quickly mute the microphone when generating a sound (e.g., a button press beep) so that the generated sound does not feed back into the microphone.

### RA7 (IO_MIC_HF_SELECT) - Microphone Audio Switching

This digital output pin is used to control an analog switch that switches between using the handset microphone audio or the external hands-free mcirophone audio.

### RA3 (IO_MIC_HF_DETECT) - External Hands-Free Microphone Detection

This digital input pin is used to detect when an external hands-free microphone is connected to the audio jack.

### UART3 - Handset Communication

This UART is used to communicate with the DiamondTel Model 92 telephone handset (see `handset.c`). It runs at 800 baud.

### UART2 - Bluetooth Module Communication

This UART is used to communicate with the BM62 Bluetooth Module (see `bt_command.c` and `bt_command_decode.c`). It runs at 115,200 baud.

### UART1 - STDIO Logging/Debugging

This UART is used for general terminal logging/debugging. STDIO is redirected to this UART. It runs at 9600 baud.

I use a USB to UART adapter (e.g., `DSD TECH SH-U09C5`) and [RealTerm](https://realterm.sourceforge.io/) to monitor output on a PC.

### UART4 - Transceiver Communication

This UART is used to communicate with the DiamondTel Model 92 telephone transceiver (see `transceiver.c`). It runs at 800 baud.

### RC4 (IO_BT_RESET) - Bluetooth Module Reset

This digital output pin is used to turn the BM62 Bluetooth module on/off via the BM62 `#reset` pin.

### RC5 (IO_BT_MFB) - Bluetooth Module UART Rx Indicator

This digital output pin is used to toggle the BM62's `MFB` pin to to indicate that it should be prepared to receive UART commands.

### RB5 (IO_PWR) - Handset Power Button

This digital input pin detects when the DiamondTel Model 92's handset power button is pressed (see `handset.c`).

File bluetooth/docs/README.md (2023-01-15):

# BM62 Bluetooth Module Docs

Useful documentation about the BM62 Bluetooth Module.

Notes:

- Some of these documents are also found in the collection of software/tools that you'll need to download to install firmware/configurations on the BM62, but are included here for convenience.
- The `BM62 Evaluation Board Guide` contains helpful information about how to use Microchip's tools to update the module with firmware/configurations.
- The `HFP v1.7.2` specification is included for convenience (this is the version fo HFP supported by the BM62).
- The `AT Command Set 3GPP TS 27.007` specification is included for convenient reference to AT commands that can be executed over Bluetooth HFP.

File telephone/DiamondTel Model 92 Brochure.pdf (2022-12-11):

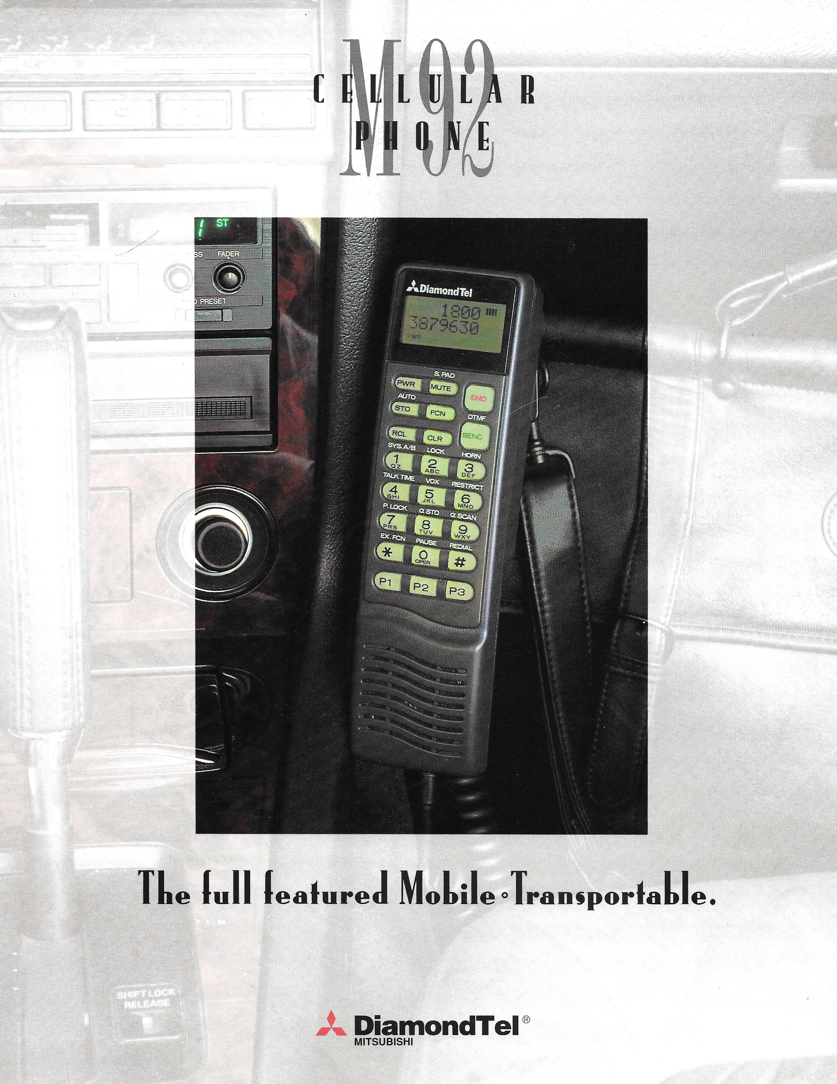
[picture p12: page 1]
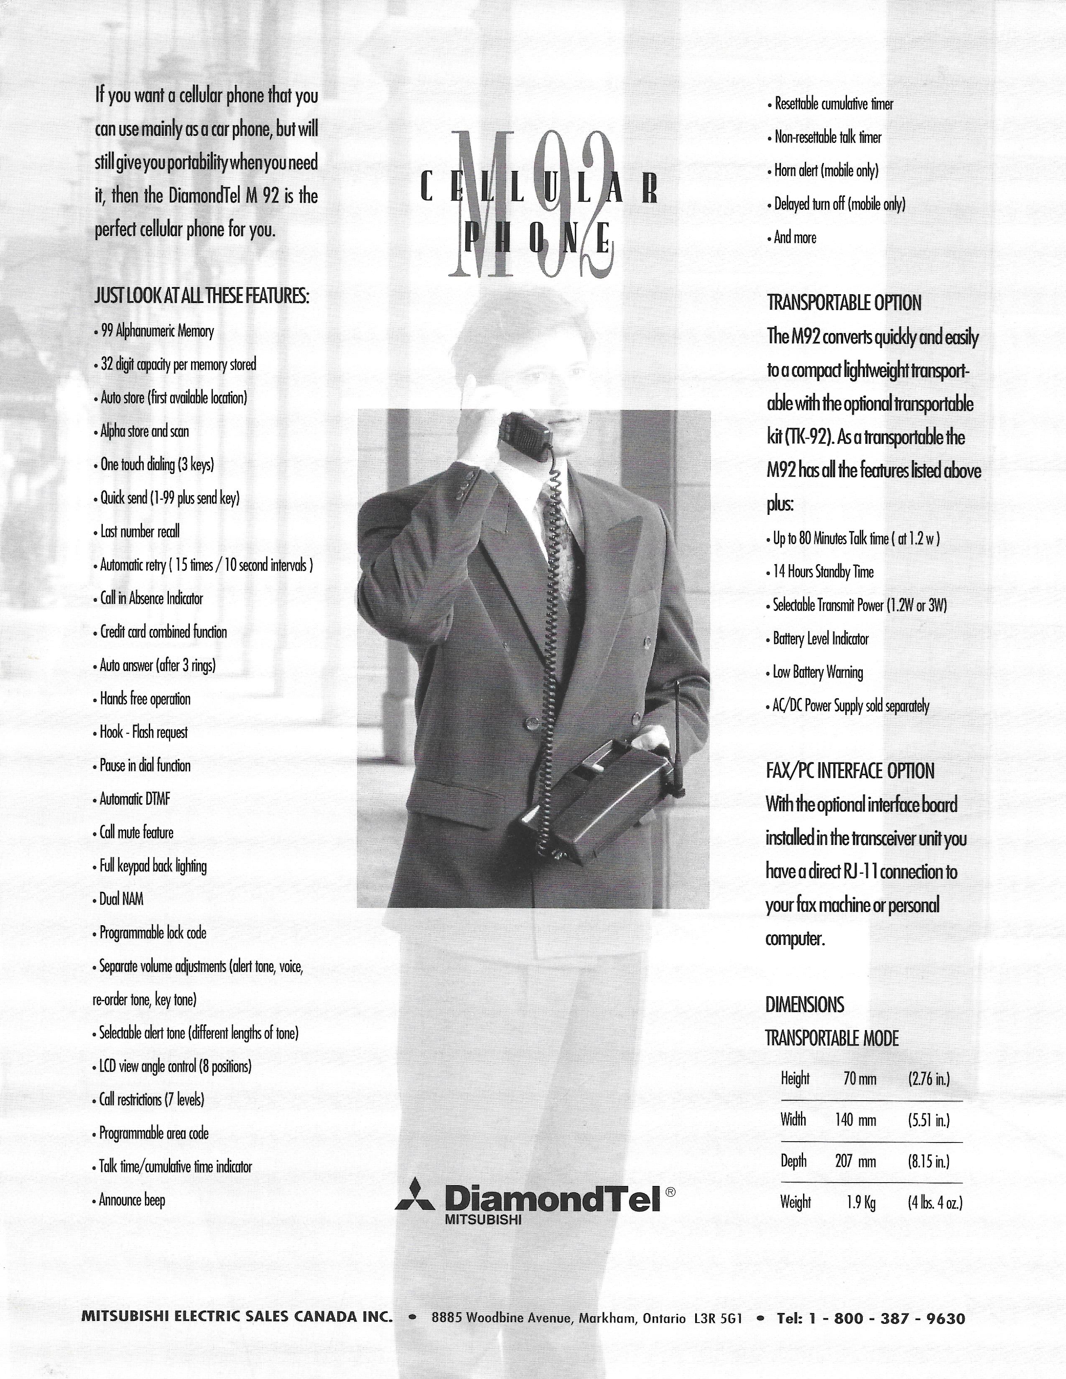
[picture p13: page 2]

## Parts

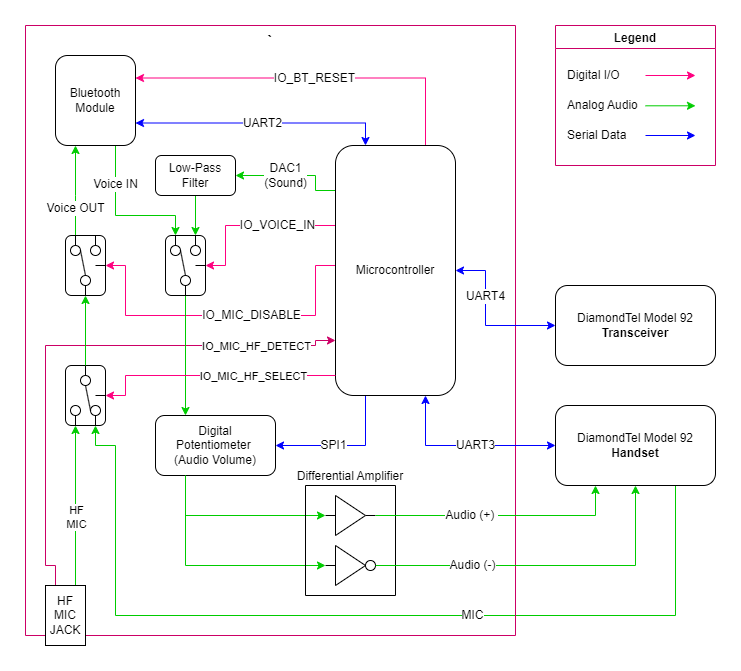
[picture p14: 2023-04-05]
readme/circuit_component_diagram.drawio.png

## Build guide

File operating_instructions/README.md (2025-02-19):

# Operating Instructions

- [Operating Instructions](#operating-instructions)
  - [Introduction](#introduction)
    - [Terminology](#terminology)
  - [Original DiamondTel Model 92 Functionality](#original-diamondtel-model-92-functionality)
  - [Enhanced Bluetooth Adapter Functionality](#enhanced-bluetooth-adapter-functionality)
    - [Bluetooth Connection Status Indicator](#bluetooth-connection-status-indicator)
    - [Bluetooth Connection Status Change Beep](#bluetooth-connection-status-change-beep)
    - [Bluetooth Automatic Reconnect](#bluetooth-automatic-reconnect)
    - [Alphanumeric Input](#alphanumeric-input)
    - [Caller ID Display](#caller-id-display)
    - [Call Waiting](#call-waiting)
    - [Bluetooth Pairing (FCN / \* / \*)](#bluetooth-pairing-fcn----)
    - [View Bluetooth Device Name (RCL / \* / \*)](#view-bluetooth-device-name-rcl----)
    - [Change Bluetooth Device Name (RCL / \* / \* / STO)](#change-bluetooth-device-name-rcl------sto)
    - [View Paired Host Phone Name (RCL / \* / #)](#view-paired-host-phone-name-rcl----)
    - [Bluetooth Manual Reconnect (FCN / PWR)](#bluetooth-manual-reconnect-fcn--pwr)
    - [Voice Dialing/Assistant (END / 1sec)](#voice-dialingassistant-end--1sec)
      - [Alternate Voice Dialing Method (Call "0" or "411")](#alternate-voice-dialing-method-call-0-or-411)
    - [Ringtone Selection (FCN / \* / 3)](#ringtone-selection-fcn----3)
    - [Games (FCN / P1/P2/P3)](#games-fcn--p1p2p3)
      - [Snake](#snake)
      - [Memory](#memory)
      - [Tetris](#tetris)
  - [Programming / Setup](#programming--setup)
    - [Entering Programming Mode](#entering-programming-mode)
    - [Viewing/Editing Programming Options](#viewingediting-programming-options)
    - [Exiting Programming Mode](#exiting-programming-mode)
    - [Programming Options](#programming-options)
      - [DUAL NO](#dual-no)
      - [NO1](#no1)
      - [NO2](#no2)
      - [SEC](#sec)
      - [DIS CU RESET](#dis-cu-reset)
      - [DIS IGN SENSE](#dis-ign-sense)
      - [DIS PWR LOCK](#dis-pwr-lock)
      - [DIS OWN TEL](#dis-own-tel)
      - [CALLER ID](#caller-id)
      - [OEM HF UNIT](#oem-hf-unit)

## Introduction

The DiamondTel Model 92 Bluetooth Adapter completely replaces the original electronics
inside the transceiver of the DiamondTel Model 92 Portable Cellular Telephone to
enable the vintage phone to connect to a modern cell phone via Bluetooth and
make/receive calls.

A primary goal during the development of this Bluetooth Adapter was to
retain/replicate much of the original phone's functionality as much as
reasonably possible. Some original features were dropped for various reasons
(irrelevant to the Bluetooth-based capabilities, high complexity:value ratio,
etc.), some original features were altered for various reasons (necessary for
proper integration of Bluetooth capabilities, technical limitations, etc.), and
some completely new features were added for various reasons (necessary for
proper integration of Bluetooth capabilities, adding modern features, or just
for fun).

### Terminology

The following terminology is used throughout these instructions to distinguish
between the different components of the system, which can become confusing due
to the involvement of two phones.

- `"the phone"` - In general, any mention of "the phone" is referring to the
DiamondTel Model 92 phone.
- `host phone` - The "host phone" is the modern cell phone that is connected via
Bluetooth to the DiamondTel Model 92 via Bluetooth Adapter.

## Original DiamondTel Model 92 Functionality

This section clarifies which of the DiamondTel Model 92's original features are
supported. What follows is a replica of the much of the table of contents from
the original `DiamondTel Model 92 Operating Instructions` with indication of
which features are replicated/supported by the Bluetooth Adapter (✔️), and which features are not replicated/supported (❌). Supported features may have
additional notes about differences compared to the original phone. Otherwise,
refer to the original operating instructions (found in the `telephone` directory
of this project) for full details.

 - ✔️ STATUS INDICATORS
    - The `||||||` signal strength indicator has additional meanings for the
    Bluetooth Adapter:
      - All bars flashing: No Bluetooth connection.
      - One bar sweeping back and forth: Bluetooth pairing.
    - All indicators otherwise work as expected. For example, the `NO SVC` and `ROAM` indicators accurately represent whether the host phone has no service or is roaming, and the `||||||` signal strength indicator represents the host phone's signal strength.    
 - ✔️ CONTROL KEYS
    - `STO`/`RCL`: Due to limited storage on the Bluetooth Adapter, only 24
    digits per phone number and 29 storage locations are supported (from 01 to 29).
 - EXTENDED BASIC FEATURES
    - See the EXTENDED FEATURE OPERATIONS section for per-feature details.
 - ✔️ BASIC OPERATION
    - ✔️ TURNING ON THE PHONE
      - After the initial power-on sequence, the `NO SVC` indicator will remain
      on and the `||||||`  signal strength bars will flash while the Bluetooth
      Adapter attempts to reconnect to the most recently connected host phone.
    - ✔️ PLACING A CALL
    - ✔️ RECEIVING A CALL
      - If Caller ID is enabled, then the Caller ID text will be displayed on
      the top row.
    - ✔️ ENDING A CALL
    - ✔️ TURNING OFF THE PHONE
      - The `PWR` button is disabled during a call like the original phone, but it is also possible to disable this feature with the `DIS PWR LOCK` programming option. When disabled, and the phone is turned off
      during a call, the call will be transferred to the host phone.
- ✔️ OTHER BASIC OPERATION
    - ✔️ VOLUME ADJUSTMENT
      - There is a 6th volume adjustment supported by the Bluetooth Adapter:
      Game Music volume. Press `FCN` then the `↑`/`↓` keys while in a game with music to adjust Game
      Music volume.
    - ✔️ STORING OFTEN-USED NUMBERS
      - Due to limited storage on the Bluetooth Adapter, only 24
      digits per phone number and 29 storage locations are supported (from 01 to 29).
      - NOTE: Original instructions for erasing an entry are misleading. There's
      no specific need to press the `CLR` key for 0.5 seconds. That is only
      needed to clear the current number if the display is not empty.
    - ✔️ RECALLING OFTEN-USED NUMBERS
      - Due to limited storage on the Bluetooth Adapter, only 24
      digits per phone number and 29 storage locations are supported (from 01 to 29).
    - ✔️ HOOK-FLASH REQUEST
      - Modern cell phone service has no concept of a "hook-flash request".
      Instead, this is now used place a call on hold or take a call off hold.
      Unfortunately, technical limitations prevent the Bluetooth Adapter from
      indicating when the call is on hold. 
      - Also used two swap between two calls (Call Waiting).
    - ✔️ LAST NUMBER REDIAL
      - NOTE: This recalls the last number called from the phone, which may not
      be the last number called from the host phone.
    - ✔️ DIALED NUMBER CHECK
      - For consistency with the reduced maximum size of stored phone numbers,
      only 24 digits can be typed. Pressing and holding `RCL` will show the ten
      most signifigant digits for as long as the `RCL` key is held.
    - ✔️ CALL IN ABSENCE INDICATOR
      - NOTE: Only indicates a missed call that occurs while the Bluetooth
      Adapter is connected to the modern phone that received the missed call.
      - If Caller ID is enabled, then the missed call's Caller ID text will be
      displayed on the top row.
    - ✔️ LOW BATTERY INDICATOR
    - ✔️ BACKLIGHTING
- EXTENDED FEATURE OPERATIONS
    - ❌ ~~SYSTEM A/B SELECTION (FCN / 1)~~
      - Irrelevant for modern phone service/tech.
    - ❌ ~~FORCING SYSTEM A/B OPERATION~~
      - Irrelevant for modern phone service/tech.
    - ❌ ~~LOCKING/UNLOCKING THE PHONE (FCN / 2)~~
      - Chose not to replicate (high complexity, low value).
    - ✔️ EXTERNAL HORN ALERT (FCN / 3)
      - Host phone must remain within Bluetooth range of the car phone for an incoming call to trigger the car horn. This is not a practically useful feature, but more of a preservation of original car phone functionality as a curiosity/demonstration.
    - ✔️ ACCUMULATED TALK TIME (FCN / 4)
    - ❌ ~~DISCONTINUOUS TRANSMISSION MODE (FCN / 5)~~
      - Irrelevant for modern phone service/tech.
    - ❌ ~~CALL RESTRICTION (FCN / 6)~~
      - Chose not to replicate (high complexity, low value).
    - ❌ ~~PROGRAMMING OF UNLOCK CODE (FCN / 7)~~
      - Chose not to replicate (high complexity, low value).
    - ✔️ ALPHABET NAME AND NUMBER STORE (FCN / 8)
      - See the [Alphanumeric Input](#alphanumeric-input) section for details about how name input is improved.
    - ✔️ ALPHABET SCAN (FCN / 9)
    - ✔️ PAUSE FUNCTION (FCN / 0)
    - ❌ ~~AUTOMATIC RETRY ON/OFF (FCN / #)~~
      - Chose not to replicate (unlikely to ever be used).
    - ✔️ CREDIT CARD NUMBER SECURITY (FCN / RCL)
      - Due to limited storage on the Bluetooth Adapter, only 6 storage locations are supported (from \*1 to \*6).
    - ✔️ ANNOUNCE BEEP ON/OFF (FCN / \* / 1)
    - ✔️ STATUS CHANGE BEEP ON/OFF (FCN / \* / 2)
    - ❌ ~~STATUS MONITOR ON/OFF (FCN / \* / 3)~~
      - Irrelevant for modern phone service/tech.
    - ❌ ~~USER PROGRAMMABLE AREA CODE (FCN / \* / 4)~~
      - Irrelevant for modern phone service/tech (always dial full phone numbers
      with area code).
    - ✔️ BATTERY VOLTAGE DISPLAY (FCN / \* / 5)
      - While viewing battery voltage, press `FCN` to toggle between viewing the
      phone's own battery voltage ("BATTERY") and viewing the host phone's
      approximate battery level ("CELLBAT").
    - ❌ ~~RF OUTPUT POWER CHANGE (FCN / \* / 6)~~
      - Irrelevant for modern phone service/tech.
    - ✔️ AUTOMATIC ANSWER (FCN / \* / 7)
    - ❌ ~~DATA INTERFACE (RJ-11) (FCN / \* / 8)~~
      - Technical limitations and complexity make this impractical to replicate.
    - ✔️ SILENT SCRATCH PAD (FCN / MUTE)
    - ✔️ AUTO STORE (FCN / STO)
    - ✔️ ONE TOUCH DIAL NUMBER STORE/RECALL (STO, RCL P1/P2/P3)
    - ✔️ AUTOMATIC DTMF (FCN / SEND)
    - ✔️ RESET CUMULATIVE TIMER (FCN / CLR)
    - ✔️ LCD VIEW ANGLE CONTROL (FCN / 2sec)
    - ✔️ OWN TELEPHONE NUMBER DISPLAY/DUAL NAM (RCL / #)
    - ✔️ MEMORY SCAN (RCL / ↑/↓)
    - ✔️ DTMF OVERDIALLING FROM MEMORY
      - Original instructions seem incorrect and did not work on the original
      phone when simulating a call with a Mobile Service Tester. Recalling a
      memory address puts the phone into "memory scan mode", where the `FCN`
      key switches to "alphabet scan mode" if the entry has a stored name.
      - With the Bluetooth Adapter, follow the original instructions, but skip
      the `FCN` step. 
      - More generally: While in a call, and while viewing a memory address
      entry (in either memory or alphabet scan mode), pressing the `SEND` key
      will send the phone number of that entry as DTMF tones. 
    - ✔️ VOICE MUTE
    - ✔️ TALK TIME
      - `CLR` key behavior differs slightly from original instructions, but
      seems to match actual original behavior: 
        - Press `CLR` to hide the call timer and view the dialed number (not the
        memory address location, and regardless of whether the dialed number is
        in the directory).
        - After clearing out the number display, the call timer can be toggled
        with the `CLR` key.
    - ❌ ~~CUMULATIVE TIMER INCREMENT~~
      - Chose to simplify by removing configurability. Cumulative timer always
      counts in 1-minute increments.
    - ❌ ~~DUAL HANDSET~~
      - Not enough information to replicate. Probably requires additional
      hardware that is not described anywhere.
    - ❌ ~~ROAM INHIBIT~~
      - Irrelevant for modern phone service/tech.

## Enhanced Bluetooth Adapter Functionality

This section explains all of the new functionality provided by the Bluetooth adapter that is not a replica of original DiamondTel Model 92 functionality.

### Bluetooth Connection Status Indicator

When the Bluetooth adapter is not connected to a host phone, all 6 bars of the `||||||` signal strength indicator will flash, and the `NO SVC` indicator will also be displayed.

If the `||||||` signal strength indicator is not flashing, then the Bluetooth adapter is connected to a host phone. The `||||||` and `NO SVC` indicators now represent the true status of the host phone.

### Bluetooth Connection Status Change Beep

If the `STATUS CHANGE BEEP` feature is enabled (refer to the original `DiamondTel Model 92 Operating Instructions`), then a sequence of 2 tones will indicate when the Bluetooth adapter connects to or disconnects from a host phone:
- Low tone, high tone: Bluetooth connected.
- High tone, low tone: Bluetooth disconnected.

### Bluetooth Automatic Reconnect

In the following situations, the Bluetooth adapter will automatically attempt to reconnect to the host phone that it was most recently paired to:
- Power on.
- Bluetooth connection lost (e.g., if you move the host phone out of range, then it will attempt to reconnect when brough back in range).

### Alphanumeric Input

See the `ALPHABET NAME AND NUMBER STORE` section of the original `DiamondTel Model 92 Operating Instructions` (specifically the section about entering a name) for a complete explanation of how alphanumeric input generally works.

The Bluetooth adapter extends this functionality by allowing lowercase letters to be entered. Each button now cycles through 6 possibilities instead of only 3.

For example, the `2` button now cycles through `A`, `B`, `C`, `a`, `b`, `c`.

### Caller ID Display

If [enabled during Programming / Setup](#programming--setup), then caller ID text (either a name or phone number) will be displayed on the handset above the "CALL" text during an incoming call, or when a missed call is displayed.

### Call Waiting

If a second call is received while you are already in a call, then you will hear your host phone's standard "call waiting" tones through the call audio, and the handset will display "CALL" just like a normal incoming call (and [Caller ID](#caller-id-display), if enabled), but the `IN USE` indicator will be displayed due to the current active call.

You have 4 options to deal with an incoming call waiting:
1. Panic and do nothing, because Call Waiting is confusing. The second caller will eventually give up or be sent to voice mail.
1. Press `SEND` to place the current call on hold and answer the incoming call.
1. Press `END` to end the current call and answer the incoming call.
1. Press `FCN`, `END` to remain in the current call and reject the incoming call.

If you chose to place the current call on hold and answer the incoming call, then the letter `W` will now be displayed to the left of the call timer display, indicating that there is another call waiting on hold.

While in a call with a second call on hold, you can manage the two calls as follows:
1. Press `SEND` to swap between the two calls.
1. Press `END` to end the current call and swap to the on-hold call.
1. Press `FCN`, `END` to end the on-hold call.

If the current call is ended by the other particpant, then the on-hold call will remain on hold. Press `SEND` to take the call off hold.

Tips for remembering how to deal with call waiting:
- The `SEND` button consistently always swaps calls without ending either call.
- The `END` button consistently always ends the current call.
- The `FCN`, `END` button sequence consistently always ends the "other" call.

### Bluetooth Pairing (FCN / \* / \*)

Press `FCN`, `*`, `*` to enter Bluetooth pairing mode and make the Bluetooth adapter discoverable to modern cell phones as a Bluetooth device.

The handset will display "PAIRING" and the Bluetooth adapter will disconnect from any host phone that it is currently connected to.

When a single bar of the `||||||` signal strength indicator begins sweeping back and forth, the Bluetooth adapter has successfully entered pairing mode, and you should be able to soon find the Bluetooth adapter on your modern cell phone's Bluetooth menu.

If you are unsure of the Bluetooth device name you should be looking for on the modern cell phone, then you may [view](#view-bluetooth-device-name-rcl----), or even [change](#change-bluetooth-device-name-rcl------sto), the Bluetooth adapter's device name before entering pairing mode.

You may cancel pairing by pressing the `CLR` button.

If pairing is not successful within about 1 minute, then the Bluetooth adapter will automatically cancel pairing and the handset will display "PAIRING TIMEOUT".

When pairing is successful, the handset will display "PAIRED:", followed by the name of the paired host phone.

NOTE: Bluetooth pairing memory is reset immediately upon entering pairing mode. Entering pairing mode, then immediately canceling pairing, is an effective way to permanently disconnect from the most recently paired host phone.

### View Bluetooth Device Name (RCL / \* / \*)

Press `RCL`, `*`, `*` to view the current name of the Bluetooth adapter. This is the name that will appear on modern cell phones when pairing or connected to the Bluetooth adapter.

The handset will display "NAME:", followed by the Bluetooth device name.

NOTE: The default name is "DiamondTel Model 92".

### Change Bluetooth Device Name (RCL / \* / \* / STO)

While [viewing the Bluetooth device name](#view-bluetooth-device-name-rcl----), press `STO` to begin entering a new name.

The handset will display "INPUT CODE". Enter your 4-digit security code (as configured during [Programming / Setup](#programming--setup)) to confirm and proceed.

The handset will now display "BT NAME ?" and you may begin [Alphanumeric Input](#alphanumeric-input) of the new Bluetooth device name, up to 32 characters.

Press `STO` to save the new name.

Clear out the entered name to return to the input prompt, then press `CLR` again to cancel the name change.

### View Paired Host Phone Name (RCL / \* / #)

Press `RCL`, `*`, `#` to view the name of the most recently paired host phone. 

NOTE: The Bluetooth adapter does not need to be currently connected to a host phone. 

The handset will display "PAIRED:" followed by the name of the paired host phone, or "[none]" if the Bluetooth adapter is not currently paired to any host phone.

Press `CLR` to exit.

### Bluetooth Manual Reconnect (FCN / PWR)

Sometimes, [Bluetooth Automatic Reconnect](#bluetooth-automatic-reconnect) may fail to reconnect to the most recently paired host phone, such as when the host phone is out of Bluetooth range for an extended period of time. Press `FCN`, `PWR` to manually initiate an attempt to reconnect.

This feature is only available while there is no active Bluetooth connection (while the `||||||` indicator is flashing).

### Voice Dialing/Assistant (END / 1sec)

When not in a call, press and hold `END` for 1 second to initiate the host phone's voice dialing/assistant (e.g., Siri on Apple phones, Google Assistant on Android phones).

The handset will display "VOICE COMMAND", then the `IN USE` indicator will display to indicate that the voice dialing/assistant is successfully activated.

You may now speak your command into the car phone's microphone. If the handset is "on hook", then an external microphone is necessary (connected to the microphone jack of the Bluetooth adapter).

Press `END` to cancel the voice dialing/assistant.

#### Alternate Voice Dialing Method (Call "0" or "411") 

Voice dialing/assistant can also be initiated by placing a call to the phone numbers "0" or "411" (traditional phone numbers that used to call an operator or directory assistance).

This alternate method allows for voice dialing/assistant to be initiated from the OEM Hands-Free system that was available for some Mitsubishi vehicles. The hands-free system can be used to speed dial one of the first 3 directory entries stored on the phone. Simply save the phone number "0" or "411" as one of the first 3 directory entries.

### Ringtone Selection (FCN / \* / 3)

Press `FCN`, `*`, `3` to select your preferred ringtone.

The handset will display "RINGER" followed by the name of the currently selected ringtone.

Press a number to select a ringtone as follows:
- `1`: `CLASSIC` (default) - A replica of the original DiamondTel Model 92 ringtone.
- `2`: `SMOOTH` - A "smoother" alternative to the `CLASSIC` ringtone.
- `3`: `NOKIA` - The classic [Nokia ringtone](https://www.youtube.com/watch?v=Vk4KK-gh0FM).
- `4`: `AXEL F` - The intro to the song ["Axel F" by Harold Faltermeyer](https://www.youtube.com/watch?v=Qx2gvHjNhQ0), made famous by the 1985 movie "Beverly Hills Cop".
- `5`: `SANS` - The catchy part of the song ["Megalovania" from the game "Undertale"](https://www.youtube.com/watch?v=0FCvzsVlXpQ) (music for the boss fight with Sans).
- `6`: `C.PHONE` - The chorus of the song ["Car Phone" by Julian Smith](https://www.youtube.com/watch?v=crm79j1qeqA).
- `7`: `TETRIS` - The [theme song from the game "Tetris"](https://www.youtube.com/watch?v=NmCCQxVBfyM).

While in the ringtone selection mode:
- Press `RCL` to toggle a preview of the selected ringtone.
- Press `↑`/`↓` to adjust the `ALERT` (ringer) volume.

Press `CLR` to exit ringtone selection.

### Games (FCN / P1/P2/P3)

Press `FCN`, then `P1`, `P2`, or `P3` to play one of three games:
- `P1`: [Snake](https://en.wikipedia.org/wiki/Snake_(video_game_genre)) - Control a snake to eat food and grow without crashing into yourself or the edge of the screen.
- `P2`: [Memory](https://en.wikipedia.org/wiki/Concentration_(card_game)) - Find pairs of matching cards. Also known as "Concentration", "Matching Pairs", etc.
- `P3`: [Tetris](https://en.wikipedia.org/wiki/Tetris) - Do I really need to describe what Tetris is?

Common features/controls in all games:
- Press `#` on the title screen to begin, or press `CLR` to exit the game.
- In general, press `CLR` on any screen within the game to back out one level toward the title screen, or press and hold `CLR` to completely exit the game.
- When prompted to choose a level, press a numbered button within the specified range. Lower numbered levels are easier. Higher numbered levels are more difficult. 
- While playing a game, press `CLR` to pause the game and exit out to a menu that allows you to choose between continuing the game, or starting a new game. Pressing `CLR` again will back out to the game's title screen.
- When an in-progress game is exited, progress is remembered until the phone is powered off. When entering the game again later, you will be prompted to choose between continuing the current game, or starting a new game.
  - Press `1` to continue the in-progress game.
  - Press `2` to start a new game.
- Press `↑`/`↓` to adjust speaker volume, which controls the volume of sound effects. `Snake` and `Tetris` have sound effects.
- Press `FCN`, `↑`/`↓` to adjust background music in games that have background music. `Tetris` has background music.
  - Background music does not play while on the title screen. This gives you a chance to adjust music volume before it begins playing on the next screen.
- When the the game ends due to a winning or losing condition, a sequence of screens will repeat to show details about the end of the game, such as your score, as well as instructions for playing another game.
  - Press `#` to play the game again with the same difficulty level.
  - Press `*` to start a new game with a different difficulty level.
  - Press `CLR` to exit to the game's title screen.

#### Snake

See the main [Games](#games-fcn--p1p2p3) section for general information that is applicable to all games.

You are a snake, represented on the screen as one or more solid rectangular blocks. The goal is to eat food (`*`) and grow as long as possible. Each piece of food adds one block to the length the snake. The snake starts as only a single block at the beginning of the game.

The head of the snake continuously moves in the last direction it was heading, and the body follows the path of the head. Press one of the following buttons to change direction:
- `2`: Up
- `8`: Down
- `4`: Left
- `6`: Right

The speed of the snake is determined by the difficulty level that was selected when starting the game.

The game ends when:
- The snake crashes into the edge of the screen.
- The snake crashes into itself.
- The snake grows to its maximum possible length (filling the entire screen).

#### Memory

See the main [Games](#games-fcn--p1p2p3) section for general information that is applicable to all games.

Several "cards" are presented face-down (represented as solid rectangular blocks). The face of each card is a symbol, and there are pairs of cards with the same symbol randomly arranged. Your goal is to find each matching pair of cards by revealing only two cards at a time.

The flashing card indicates the position of your cursor.

Controls:
- `2`: Move Up
- `8`: Move Down
- `4`: Move Left
- `6`: Move Right
- `1`/`3`: Move Left/Right, but skip over any revealed cards to the next face-down card, and wrap around to the next/previous row. This allows you to move around more quickly.
- `5`: Reveal the selected face-down card.

The first revealed card will remain revealed until you reveal a second face-down card. The pair of revealed cards will then flash a couple times. If the pair is a match, then they will remain revealed. Otherwise, they will be turned face-down again.

The number of cards is determined by the difficulty level that was selected when starting the game.

The game ends when all pairs of cards have been matched/revealed.

The end-game screen will indicate how many moves (pairs of revealed cards) you made. A lower number of moves is better.

#### Tetris

See the main [Games](#games-fcn--p1p2p3) section for general information that is applicable to all games.

Due to display limitations on the phone, this game of Tetris is played sideways. Pieces "fall" from right to left. There is also a minimum of 2 consecutive lines that must be filled in order to clear lines, and a maximum of 3 consecutive lines can be filled/cleared at a time.

Controls:
- `1`: Rotate piece counter-clockwise.
- `3`: Rotate piece clockwise.
- `2`: Move piece up.
- `5`: Move piece down.
- `4`: "Drop" piece rapidly to the left, while held down.

The scoring and the speed at which pieces fall is determined by the difficulty level.

Earn points by clearing lines. The base point value is determined by the number of lines simultaneously cleared:
- `2 lines`: 1 point
- `3 lines`: 3 points

This base point value is multiplied by the current diffulty level.

The difficulty level that was selected when starting the game only determines the initial difficulty level. Difficulty will automatically increase while playing as you reach milestones of total number or lines cleared as follows:
- `Level 2`: After 20 lines are cleared.
- `Level 3`: After 40 lines are cleared.
- `Level 4`: After 60 lines are cleared.
- `Level 5`: After 80 lines are cleared.
- `Level 6`: After 100 lines are cleared.
- `Level 7`: After 120 lines are cleared.
- `Level 8`: After 140 lines are cleared.
- `Level 9`: After 160 lines are cleared.

For maximum scoring, it is best to start at a higher level, and try to clear 3 lines at a time as much as possible, to maximize points per line cleared.

The game ends when pieces have stacked up to the point that there is no room for the next piece to be placed on the board.

##### High Score

A single high score is stored in memory for `Tetris`, along with player initials.

When a game ends and your score is higher than the current highs core, you will be prompted to enter your initials. Enter up to 3 letters/numbers as [Alphanumeric input](#alphanumeric-input), then press `STO` to save the initials, or press `CLR` to skip entering initials (initials will default to `???`).

You can view the current high score at any time from the title screen of the game by pressing `RCL`. 

While viewing the high score, you can choose to reset the high score by pressing `FCN`, `CLR`, then entering your 4-digit security code (as configured during [Programming / Setup](#programming--setup)). 

## Programming / Setup

The Bluetooth Adapter supports a "programming mode" for configuring core options
of the phone, much like the original DiamondTel Model 92. However, it is much
simpler than the original programming mode because there is no need to setup
cell phone carrier settings.

### Entering Programming Mode

Entering programming mode is done the same as the original phone:

1. Turn the phone on.
1. After the initial startup sequence (as soon as the `||||||` signal strength indicators start,
flashing), Press and hold the `CLR` key while entering the code `1591426`. This
must be completed within 10 seconds of startup.
    - NOTE: This code can only be used to enter programming mode up to 3 times.
    An alternate "programming reset" code (`8291112`) can ALWAYS be used to
    enter programming mode, and will also reset the ability to use the `1591426`
    code. This mimics the original phone behavior for maximum authenticity.
    The standard (3-times-only) code is included in the original Operating
    Instructions, while the "programming reset" code was a "secret" code known to
    "authorized" personnel only. The "programming reset" code is therefore the 
    more convenient code to use for programming.
1. If successful, the Bluetooth Adapter will disconnect from the host phone, and 
you will see the first programming option flashing on the screen.

### Viewing/Editing Programming Options

When first entering programming programming mode, you will see the first
option's label and value flashing on the screen. Each programming option has a 
simple numeric value. From here, you can either advance to the next option by
pressing `SEND`, or enter a new value for the current option.

While a programming option is flashing on the screen, begin entering a
numeric value to edit its value. The display will clear and stop flashing,
showing only the value you are entering.

Press `CLR` to cancel editing and return to viewing the current value of the
programming option.

Press `SEND` to save the new value. If the entered value is valid, it will be 
saved and programming will advance to the next option. If the entered value is
invalid, you will remain in editing mode. From here, you can either continue 
typing more digits if necessary to make the value valid, or cancel editing and 
start over.

### Exiting Programming Mode

While viewing (not editing) a programming option, press the `END` key. The
phone will restart with the new programming options applied.

NOTE: Each change to a programming option is saved immediately. There is no way
to cancel/exit programming mode without applying the changes you have already
made.

### Programming Options

#### DUAL NO

If enabled, then two phone numbers are associated with this phone instead of 
only one. See the `OWN TELEPHONE NUMBER DISPLAY/DUAL NAM` section of the
original `DiamondTel Model 92 Operating Instructions` for details about
switching between between dual numbers.

**Valid Values**:
- `0`: Dual Number disabled.
- `1`: Dual Number enabled.

**Default Value**: `0`

#### NO1

This is the primary phone number associated with this phone. This is entirely
cosmetic and has no impact on functionality (it does not need to match your
actual phone number). This number may be displayed during the power-on sequence,
or manually recalled (See the `OWN TELEPHONE NUMBER DISPLAY/DUAL NAM` section of
the original `DiamondTel Model 92 Operating Instructions`).

**Valid Values**: Any 7-digit or 10-digit number.

**Default Value**: `0000000000`

#### NO2

Only available if the `DUAL NO` programming option is enabled.

This is the secondary phone number associated with this phone. This is entirely
cosmetic and has no impact on functionality (it does not need to match your
actual phone number). This number may be displayed during the power-on sequence,
or manually recalled (See the `OWN TELEPHONE NUMBER DISPLAY/DUAL NAM` section of
the original `DiamondTel Model 92 Operating Instructions`).

**Valid Values**: Any 7-digit or 10-digit number.

**Default Value**: `0000000000`

#### SEC

This is a 4-digit security code that must be entered to access certain features
of the phone.

**Valid Values**: Any 4-digit number.

**Default Value**: `0000`

#### DIS CU RESET

Disables the ability to reset the cumulative talk timer. See the 
`RESET CUMULATIVE TIMER` section of the original
`DiamondTel Model 92 Operating Instructions`.

**Valid Values**:
- `0`: Cumulative timer reset is enabled.
- `1`: Cumulative timer reset is disabled.

**Default Value**: `0`

#### DIS IGN SENSE

Disables vehicle ignition sensing.

When NOT disabled, and if external power is connected, then 
the phone cannot be powered on unless the vehicle ignition is on. Turning the vehicle ignition off
will power the phone off. If the phone was last powered off by vehicle ignition, then turning vehicle
ignition on will power the phone on.

When disabled, the vehicle ignition is ignored and the phone can be manually powered on/off at any
time. Vehicle ignition will not power the phone on or off.

**Valid Values**:
- `0`: Vehicle ignition sensing is enabled.
- `1`: Vehicle ignition sensing is disabled.

**Default Value**: `0`

#### DIS PWR LOCK

Disables power-off lock-out behavior when in a call.

When NOT disabled, the phone cannot be powered off during a call. The `PWR` button is disabled.
If mounted in a vehicle, and vehicle ignition is turned off, then the phone will automatically power off
after the call ends or the Bluetooth connection is lost.

When disabled, the phone can be powered during a call, and the call will be transferred to the host phone. 

**Valid Values**:
- `0`: Power-off lock-out is enabled.
- `1`: Power-off lock-out is disabled.

**Default Value**: `0`

#### DIS OWN TEL

Disables the display of the phone's own configured phone number (`NO1` or `NO2`
programming option) during the phone's power-on sequence.

**Valid Values**:
- `0`: Own telephone number display is enabled.
- `1`: Own telephone number display is disabled.

**Default Value**: `0`

#### CALLER ID

Enables Caller ID for incoming calls.

**Valid Values**:
- `0`: Caller ID is disabled (authentic original behavior).
- `1`: Caller ID is enabled: display name (phone number is displayed if name is
unavailable).
- `2`: Caller ID is enabled: display phone number.

**Default Value**: `0`

#### OEM HF UNIT

Adjusts some behavior for compatibility with the OEM Hands-Free Controller Unit
that was available for some Mitsubishi vehicles as part of a fully integrated
car phone accessory. When enabled, the adjusted behavior is only applied when
an external microphone connection is detected. For example, Caller ID (if 
enabled) is automatically disabled to avoid interfering with the Hands-Free
Controller's ability to properly detect the start and end of an incoming call.

This option should be enabled only if you are using the Bluetooth Adapter
together with the OEM Hands-Free Controller Unit.

**Valid Values**:
- `0`: OEM Hands-Free Controller compatibility is disabled.
- `1`: OEM Hands-Free Controller compatibility is enabled.

**Default Value**: `0`

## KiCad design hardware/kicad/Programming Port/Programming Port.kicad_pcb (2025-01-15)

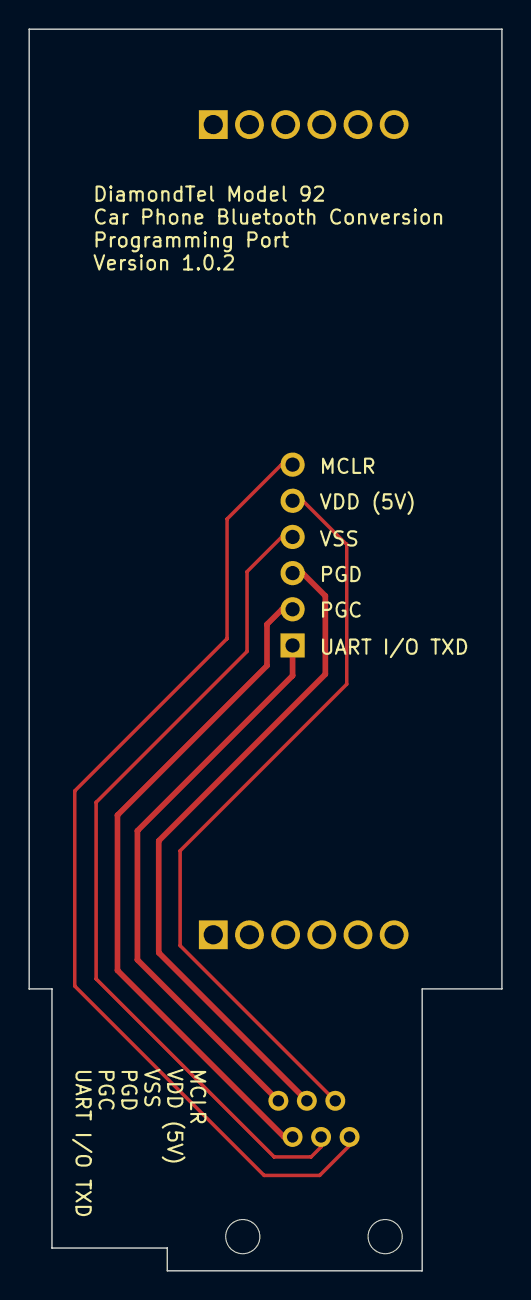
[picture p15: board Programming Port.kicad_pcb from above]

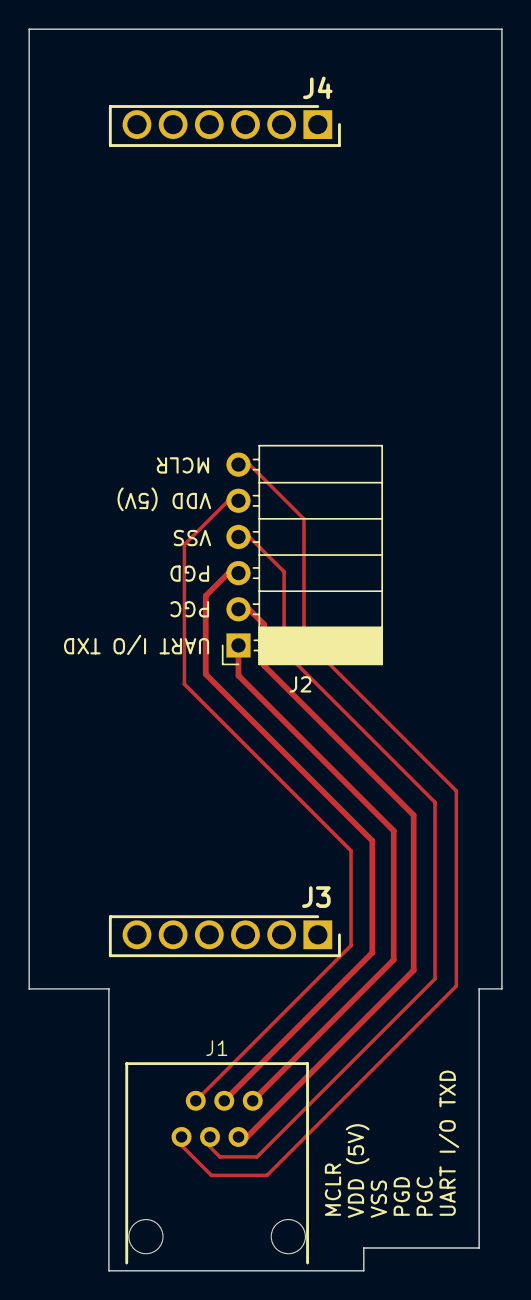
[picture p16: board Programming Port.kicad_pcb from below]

Board: 2 copper layers, 33.2 x 87.2 mm, 4 parts (4 on the bottom side), 6 nets.

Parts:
J1: TM5RE1-66
J2: PPTC061LGBN-RC; PinSocket_1x06_P2.54mm_Horizontal
J3, J4: PPTC061LFBN-RC; RHDR6W80P0X254_1X6_1574X254X870P_1MM_SPACER

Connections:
unnamed: J1.6, J2.1
unnamed: J1.5, J2.2
unnamed: J1.4, J2.3
unnamed: J1.3, J2.4
unnamed: J1.2, J2.5
unnamed: J1.1, J2.6

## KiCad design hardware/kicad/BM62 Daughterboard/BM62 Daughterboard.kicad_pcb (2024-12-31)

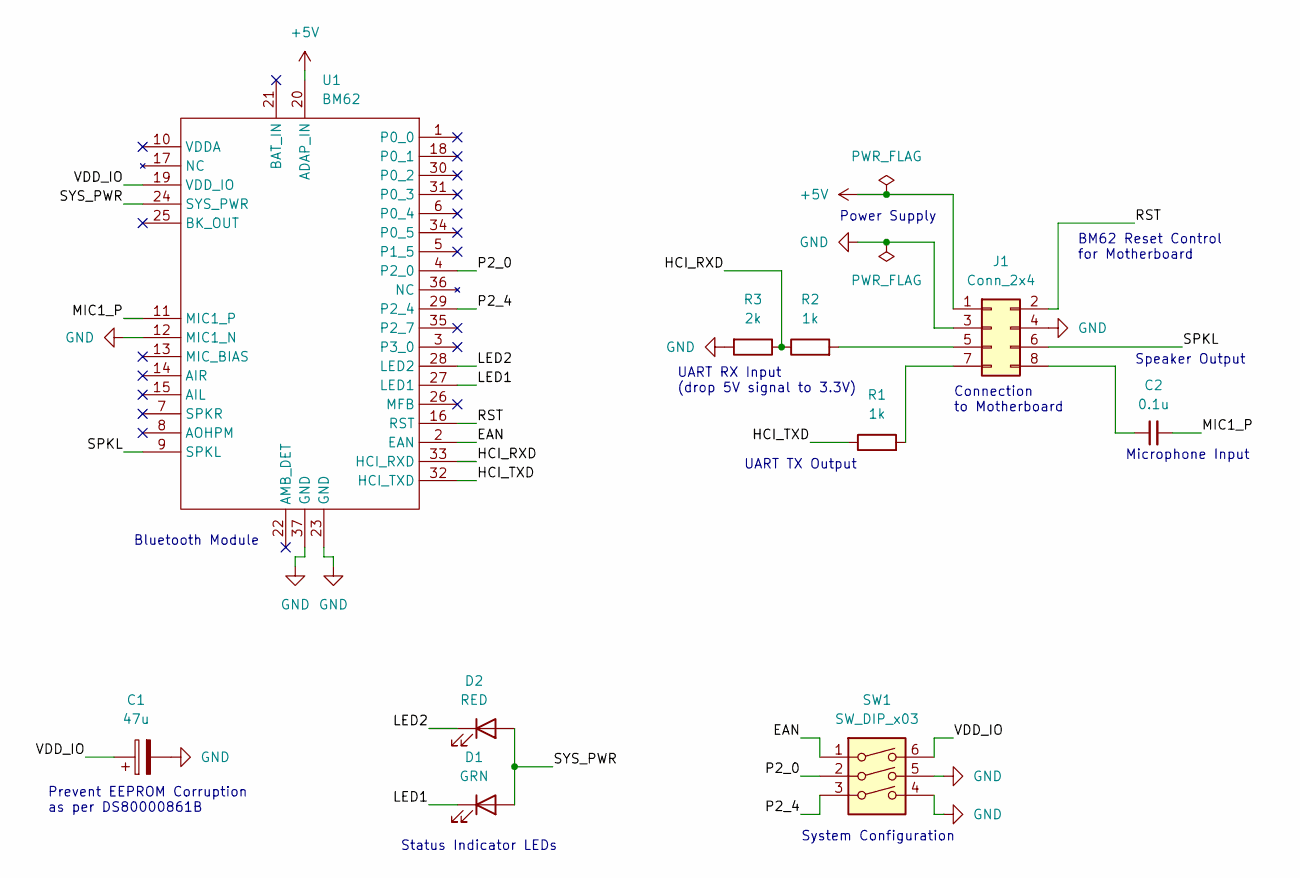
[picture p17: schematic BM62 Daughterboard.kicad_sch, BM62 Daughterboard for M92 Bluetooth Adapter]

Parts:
C1: 47u; CP_Elec_6.3x5.4; Manufacturer_Part_Number EXV476M016A9GAA; Mouser Part Number 80-EXV476M016A9GAA
C2: 0.1u; C_1206_3216Metric_Pad1.33x1.80mm_HandSolder; Manufacturer_Part_Number C1206C104J4HACTU; Mouser Part Number 80-C1206C104J4HACTU
D1: GRN; LED_1206_3216Metric_Pad1.42x1.75mm_HandSolder; Manufacturer_Part_Number HSME-C150; Mouser Part Number 630-HSME-C150
D2: RED; LED_1206_3216Metric_Pad1.42x1.75mm_HandSolder; Manufacturer_Part_Number HSMC-C150; Mouser Part Number 630-HSMC-C150
J1: Conn_2x4; PinHeader_2x04_P2.54mm_Horizontal; Manufacturer_Part_Number 90122-0124; Mouser Part Number 538-90122-0124
R1, R2: 1k; R_1206_3216Metric_Pad1.30x1.75mm_HandSolder; Manufacturer_Part_Number CR1206-FX-1001ELF; Mouser Part Number 652-CR1206FX-1001ELF
R3: 2k; R_1206_3216Metric_Pad1.30x1.75mm_HandSolder; Manufacturer_Part_Number CR1206-FX-2001ELF; Mouser Part Number 652-CR1206FX-2001ELF
SW1: SW_DIP_x03; DS04254103BKSMT; Manufacturer_Part_Number DS04-254-1-03BK-SMT; Mouser Part Number 490-DS04254103BK-SMT
U1: BM62; Microchip BM62; Manufacturer_Part_Number BM62SPKS1MC2-0001AA; Mouser Part Number 579-62SPKS1MC20001AA

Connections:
+5V: J1.1, U1.20 (ADAP_IN)
/EAN: SW1.1, U1.2 (EAN)
/HCI_RXD: R2.1, R3.1, U1.33 (HCI_RXD)
/HCI_TXD: R1.1, U1.32 (HCI_TXD)
/LED1: D1.1 (K), U1.27 (LED1)
/LED2: D2.1 (K), U1.28 (LED2)
/MIC1_P: C2.2, U1.11 (MIC1_P)
/P2_0: SW1.2, U1.4 (P2_0)
/P2_4: SW1.3, U1.29 (P2_4)
/RST: J1.2, U1.16 (RST)
/SPKL: J1.6, U1.9 (SPKL)
/SYS_PWR: D1.2 (A), D2.2 (A), U1.24 (SYS_PWR)
/VDD_IO: C1.1, SW1.6, U1.19 (VDD_IO)
GND: C1.2, J1.3, J1.4, R3.2, SW1.4, SW1.5, U1.12 (MIC1_N), U1.23 (GND), U1.37 (GND)
unnamed: J1.5, R2.2
unnamed: J1.7, R1.2
unnamed: C2.1, J1.8

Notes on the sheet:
Status Indicator LEDs
BM62 Reset Control for Motherboard
Prevent EEPROM Corruption as per DS80000861B
System Configuration
UART TX Output
Connection to Motherboard
Power Supply
Bluetooth Module
Speaker Output
Microphone Input
UART RX Input (drop 5V signal to 3.3V)

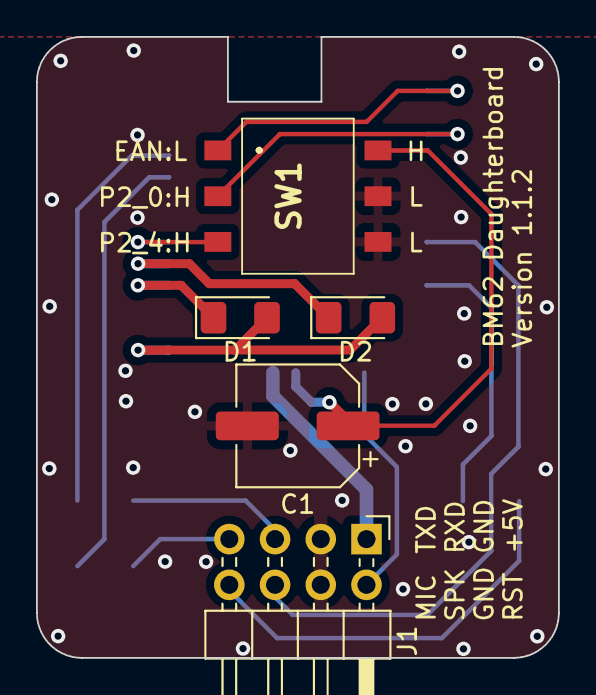
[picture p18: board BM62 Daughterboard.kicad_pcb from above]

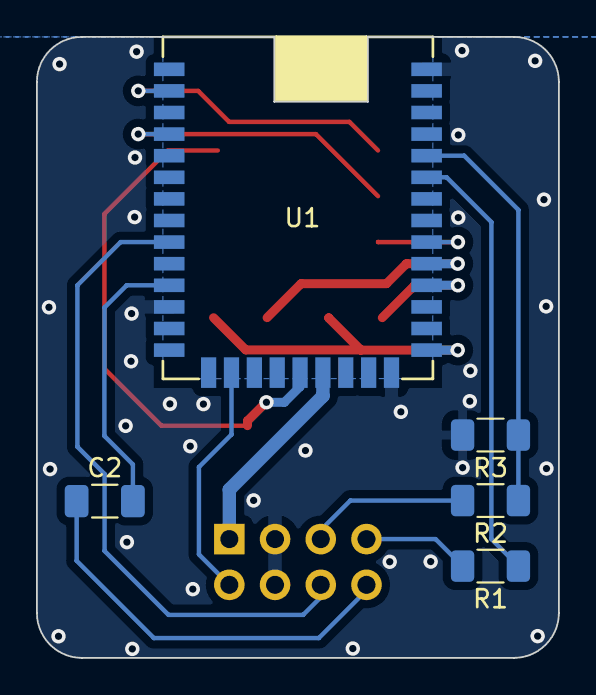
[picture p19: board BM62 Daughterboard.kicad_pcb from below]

Board: 2 copper layers, 29.0 x 34.5 mm, 10 parts (5 on the bottom side), 17 nets.

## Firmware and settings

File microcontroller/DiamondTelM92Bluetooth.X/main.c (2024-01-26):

/**
  Generated Main Source File

  Company:
    Microchip Technology Inc.

  File Name:
    main.c

  Summary:
    This is the main file generated using PIC10 / PIC12 / PIC16 / PIC18 MCUs

  Description:
    This header file provides implementations for driver APIs for all modules selected in the GUI.
    Generation Information :
        Product Revision  :  PIC10 / PIC12 / PIC16 / PIC18 MCUs - 1.81.8
        Device            :  PIC18F27Q43
        Driver Version    :  2.00
*/

/*
    (c) 2018 Microchip Technology Inc. and its subsidiaries. 
    
    Subject to your compliance with these terms, you may use Microchip software and any 
    derivatives exclusively with Microchip products. It is your responsibility to comply with third party 
    license terms applicable to your use of third party software (including open source software) that 
    may accompany Microchip software.
    
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
    IN NO EVENT WILL MICROCHIP BE LIABLE FOR ANY INDIRECT, SPECIAL, PUNITIVE, 
    INCIDENTAL OR CONSEQUENTIAL LOSS, DAMAGE, COST OR EXPENSE OF ANY KIND 
    WHATSOEVER RELATED TO THE SOFTWARE, HOWEVER CAUSED, EVEN IF MICROCHIP 
    HAS BEEN ADVISED OF THE POSSIBILITY OR THE DAMAGES ARE FORESEEABLE. TO 
    THE FULLEST EXTENT ALLOWED BY LAW, MICROCHIP'S TOTAL LIABILITY ON ALL 
    CLAIMS IN ANY WAY RELATED TO THIS SOFTWARE WILL NOT EXCEED THE AMOUNT 
    OF FEES, IF ANY, THAT YOU HAVE PAID DIRECTLY TO MICROCHIP FOR THIS 
    SOFTWARE.
*/

// Disable "unused function" warning
#pragma warning disable 520

#include "mcc_generated_files/mcc.h"
#include "src/app.h"

/*
                         Main application
 */
void main(void)
{
    // Initialize the device
    SYSTEM_Initialize();
    
    APP_Initialize();

    INTERRUPT_GlobalInterruptHighEnable();
    INTERRUPT_GlobalInterruptLowEnable();

    while (1)
    {
      APP_Task();
    }
}
/**
 End of File
*/

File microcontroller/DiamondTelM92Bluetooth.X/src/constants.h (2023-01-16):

/** 
 * @file
 * @author Jeff Lau
 *
 * General constants for this project.
 */

#ifndef CONSTANTS_H
#define	CONSTANTS_H

#ifdef	__cplusplus
extern "C" {
#endif

/**
 * Length of a standard phone number (including area code).
 * 
 * Example: 3138675309 (traditionally formatted as 313-867-5309)
 */
#define STANDARD_PHONE_NUMBER_LENGTH (10)

/**
 * Length of a short phone number (excluding area code).
 * 
 * Example: 8675309 (traditionally formatted as 867-5309)
 */
#define SHORT_PHONE_NUMBER_LENGTH (7)
  
/**
 * Maximum length of an "extended" phone number (to allow for pause characters, 
 * DTMF sequences, credit card memory location references).
 * 
 * Example: 3138675309P2#M*1#
 */
#define MAX_EXTENDED_PHONE_NUMBER_LENGTH (24)
  
/**
 * Length of a credit card number.
 */
#define CREDIT_CARD_NUMBER_LENGTH (16)

/**
 * Number of digits in a security code.
 */
#define SECURITY_CODE_LENGTH (4)
  
/**
 * Maximum length of a string containing player initials 
 * (for high scores in games).
 */  
#define MAX_PLAYER_INITIALS_LENGTH (3)

/**
 * Caller ID modes
 */
typedef enum CALLER_ID_Mode {
  /**
   * Caller ID is off/disabled.
   */
  CALLER_ID_Mode_OFF,
  /**
   * Caller ID is enabled, with preference to display name.
   * (displays phone number if name is not available).
   */
  CALLER_ID_Mode_NAME,
  /**
   * Caller ID is enabled, with preference to display phone number.
   * (displays name if phone number is not available).
   */    
  CALLER_ID_Mode_NUMBER
} CALLER_ID_Mode;  

/**
 * Number of Caller ID modes.
 */
#define CALLER_ID_MODE_COUNT (3)
  
#ifdef	__cplusplus
}
#endif

#endif	/* CONSTANTS_H */

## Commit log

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2022-12-16 Add handset UART spreadsheet, and add sound frequencies to README
    [DiamondTel Model 92 UART Events and Commands.xls]
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2022-12-19 Disable BM62 UART CPU Idle Mode
    BM62 UART CPU Idle Mode seems to cause glitches in incoming phone call audio.
2022-12-20 Adjust audio balance between MCU audio and Bluetooth audio
    Changed DAC config to use FVR at 2.048V as it's positive reference.
    This allows the SINE table for tone output to use the full range of 0-255 without nearing limits of the Op Amp buffer.
    Circuit was changed to to use parallel unity and inverting unity amplifiers for the differential amplifier for audio output. Previously it was a 1/2 gain feeding into an inverting unity. This simplifies and accounts for the DAC output being about half peak-peak of what it used to be.
    The BM62 config was also updated to reduce voice output gain to account for the 1/2 gain amplifier being changed to unity gain.
2022-12-22 Update BM62 to firmware 2.1.5
    Update BM62 to firmware 2.1.5. This includes new firmware file (only one now), new UI/DSP config, and new "compiled" full EEPROM files.
    A new UITool setting was enabled to only accept connection requests from paired devices when not in pairing mode.
    The README for bluetooth config is rewritten to explain how to install the new firmware and the software/config.
2022-12-22 Replace BM62 UART command set documentation with new version
2022-12-23 Add factory reset and reset paired devices features
    [bt_command_send.c]
2022-12-24 Defer storage of volume level changes to avoid excessive EEPROM writes
    [volume.c]
2022-12-24 Improve EEPEOM code
    Fix a bug in EEPROM_IsDoneWriting() - it was not taking into consideration the current deferred write that was being written (resulting in the phone rebooting before EEPROM erase was complete when performing a factory reset).
    Add a few while(NVMCON0bits.GO) loops at the beginnings of functions that perform EEPROM read/writes to absolutely guarantee no interference with pending async writes.
    Clean up a few unnecessary while(NVMCON0bits.GO) loops that were previously added in hopes of fixing some write bugs (but it was actually incomplete writes due to the EEPROM_IsDoneWriting bug).
    Removed the repeatingByte field from the buffered write header to reduce the size of hea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
2022-12-25 Fix Tetris game over button handling bug
    Fix bug in Tetris game over screens where button presses were ignored on one of the screens.
2022-12-29 Make button beep durations more consistent
    Applied consistent rules to button beep durations, using original phone behavior as inspiration.
    In general, the beep lasts as long as a button is held down. Exceptions are:
    - During programming, beep durations are limited (consistent with original phone).
    - If behavior is triggered by the button being held, then the beep is stopped to provide feedback that something has happened and that holding the button longer will not do anything more (consistent 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
    A significant (and intentional) inconsistency from original phone behavior is that behavior triggered by holding the CRL b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
2022-12-29 Rename some "lifecycle" functions for consistency.
    Rename some "lifecycle" functions for consistency:
    - Initialization functions end in "_Initialize".
    - Main task loop functions end in "_Task".
    - Timer handler functions end in "_Timer_Tick", "_Timer10MS_Tick", or "_Timer1MS_Tick".
2022-12-29 Rename all Timer_Tick functions to Timer_Interrupt to clarify that it is interrupt code
2022-12-30 Improve the sound engine
    Rework the sound engine a bit to improve handling of volume volume level "OFF". Fixed various bugs, such as "silent" foreground sounds interrupting a background sound, and sounds sometimes still being played when the volume is OFF (which is still slightly audible even though the volume potentiometer is set to lowest level possible)
    - Add volume level get/set methods to the SOUND module and update other code to use these functions instead of directly calling methods of the VOLUME module. This allows the sound engine to react to changes in volume (between OFF and not OFF) for a sound that is currently playing.
    - Greatly simplify the sound engine to completely re-eval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
2023-01-07 Implement status beeps for service and roaming status changes
    Play a 0.5s high tone beep when service or roaming status changes (same as original phone behavior), if enabled.
    A 1s cooldown period prevents rapid back-to-back beeps when both roaming and service status change.
    The Bluetooth connection status beep also starts the cooldown timer, but is not prevented by the cooldown timer (Bluetooth connection status beep always takes precedence).
    Also updated the 1-minute talk time warning beep to be the same 0.5s status beep for consistency with the original phone.
2023-01-09 Add support for voice commands (Siri, Google Assistant)
    While no call actions are active/pending, pressing and holding the SEND button for a short time will initiate voice command (Siri, Google Assistant).
    While in voice command state, "VOICE COMMAND" is displayed and the user can only adjust the volume, or cancel the voice command by pressing END.
    [bt_command_send.c]
2023-01-14 Rework outgoing call and call timer behavior to match original phone
    When an outgoing call is pending:
    - Called number remains displayed until the call is connected (no more "CALLING" display and clearing out the input).
    - All button presses are ignored (except PWR, END, and volume UP/DOWN).
    When a call connects:
    - The call timer is displayed, but the called number remains as the current input value
    Updated call timer behavior:
    - If call timer is displayed, pressing CLR will "hide" the timer and return to the number input.
    - Call timer is re-displayed whenever returning from another "view".
    - Call timer can be manually re-displayed by pressing CLR when the number input is empty.
    - Fixed bu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
2023-01-15 Improve outgoing call and call timer behavior again
    Previous update to outgoing call and call timer behavior wasn't quite correct according to the original phone behavior.
    Updates/improvements to call timer behavior:
    - If call timer was displayed when "navigating" to another screen, the call timer is now redisplayed upon "returning", even if the number input is populated.
    - Call timer now displays during a call immediately upon clearing out the current number.
    - After hiding the call display, clearing out the number input, then hiding the call timer again, the call timer will be redisplayed again automatically after "navigating' to another screen then returning.
    Big improvement to outgoing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
2023-01-16 Caller ID and externally-initiated outgoing call improvements
    - Added configurability to caller ID to choose whether to prefer displaying the name or the number.
    - Format the caller ID phone number nicely.
    - When retrieving the phone number of an externally-initiated outgoing call, simplify the number before displaying/storing to avoid a leading "+" and remove unnecessary international dialing codes for US-to-US calls.
    [bt_command_send.c, constants.h]
2023-01-16 Switch voice command button from SEND to END
    Voice command is now triggered by holding the END button for a short time instead of holding the SEND button.
    This allows voice command to be triggered regardless of whether a number is currently typed on the screen, or any other situation where pressing the SEND button will place a call.
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2023-02-01 Improvements for compatibility with the Hands-Free system
    * Improve SOUND module in multiple ways, primarily driven by the need to recover from the Hands-Free system muting all of the handset audio during a hands-free call, and to prevent button beeps from playing while handling the rapid simulated button sequence for speed dialing through the Hands-Free controls. The resulting changes (some very tangential to the main goal) ended up improving audio quality in general by reducing audio clicks/pops when turning speakers on just before playing a sound, and always turning the handset speaker off when not actively playing a sound to avoid constant output of audio circuit noise.
    * Add ability to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
2023-02-12 Improve compatibility with the Hands-Free Controller
    * Disable Caller ID when in "vehicle mode", because caller ID breaks out of hands-free "incoming call" mode.
    * Send specific sequences of commands that the Hands-Free Controller expects to signal the start and end of an incoming call.
    * Get rid of the flashing IN USE indicator for Call Waiting, because it would switch the Hands-Free Controller in/out of "in call" mode. Need to come up with a replacement indication later.
2023-02-12 Fix bug where END button doesn't always end the active call.
    Move some END button handling so that ending a call can be performed at any time regardless of app state.
    Also reorganized some other common handset event handling, such as moving microphone enabling/disabling behavior to the SOUND module.
2023-02-12 Enable weak pull-up on UART3 RX pin
    This change removes the need for an external pull-up resistor to prevent random garbage input when nothing is connected to UART3 for STDIO.
2023-02-12 Fix recent regression where PWR button would not trigger the power-down beep
2023-02-13 Call Waiting improvements
    * Display a "W" indicator with the call timer when there's waiting call on hold.
    * Display a "W" indicator with the "CALL" message when there's an incoming waiting call.
    * Force the call timer to be displayed when returning when returning to an active call state after an incoming waiting call (help ensure that the new "W" indicator will be displayed if there is now a waiting call on hold).
    * Fix a bug where the Hands-Free module would not properly set itself into "incoming call" mode when transitioning straight from "incoming waiting call" state to "incoming call" state, because the active call ended from the other end.
2023-02-17 Improve PWR button handling
    * Initialize PWR button state correctly based on current PWR button input value.
    * Use I/O interrupt-on-change to detect changes instead of reading the pin value repeatedly to test for changes.
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2023-02-22 Add external power detection, external mic detection, and OEM hands-free support configuration
    * Removed the manual "CARRIED" vs "VEHICLE" mode selection and replaced with automatic detection of external power (inferred from back-light on/off commands received from the transceiver). Handset is allowed to go "idle" (back-light off, sound off) after 10 seconds of inactivity if external power is NOT connected.
    * Added external microphone connection detection via a digital input pin.
    * Added a new programmable setting to enable OEM Hands-Free integration support. When enabled, and an external microphone is connected, then Caller ID is automatically disabled to prevent interference with Hands-Fre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
2023-02-25 Minor alignment fix to circuit component diagram
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2023-03-04 Fix initialization of VOLUME module to reset a timeout before its state is checked.
    [volume.c]
2023-03-04 Fix bug where LOW BATTERY message is not cleared when typing a digit.
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2023-03-19 Minor audio fixes
    * When turning the loudspeaker off, place the command at the front of the UART send buffer to ensure it is turned off ASAP (minimizing unwanted noise when not actively producing a sound).
    * Send a sacrificial null command immediately after enabling Master Audio on the handset to avoid occasional corrupted handset command caused by loud audio pop.
2023-03-19 Update circuit layout, README, and datasheets.
    Update circuit layout, README, and datasheets to adjust for the components I ended up ordering, and adjusting the layout to fid in the project box I ordered. The biggest change is trading out the pair of INA105 op amps for single DRV134 differential audio driver. I'm also switching to a different (but similar) transistors whose pinout is reversed.
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2023-05-21 Circuit layout improvements
    * Increase amplification of external microphone to better match handset microphone.
    * Connect analog switch IC "enable" pin to ground to fix occasional unintentional sound disabled (due to floating digital input pin).
2023-12-05 Fix sound interruption when ending a call
    Fix a button beep sound interruption when ending a call caused by a specific sequence of commands that are needed for OEM Hands-Free Controller compatibility (to deal with switching between car audio output and phone audio output).
    When NOT using the OEM Hands-Free Controller, these additional commands are unnecessary and interrupt sound output.
    Additional commands are now executed only when the OEM Hands-Free Controller is believed to be connected.
2024-01-06 Update hardware to use pair of INA105 for differential audio output
    Improved audio quality (eliminated digital UART noise from handset) by using 2 INA105's to produce differential audio output. Also made other minor changes.
2024-01-21 Rework MCU config and code for new standalone hardware design
    MCU config and code is reworked for new hardware design that eliminates interface with the original car phone transceivers and instead manages its own power on/off behavior, battery level detection, external power connection detection, vehicle ignition detection, etc.
    [battery.c, bt_command_send.c]
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2024-01-22 Swap UART3 TX/RX pin assignments for better PCB layout
2024-01-23 Consolidated all END button logic into one place, fixing some bugs.
    Much of the END button behavior needs to happen regardless of app state, but the logic was scattered. One bug was that it was impossible to end an outgoing call while it was still pending.
    END button logic is now all consolidated in one place for simplicity, all known END button bugs are fixed.
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2024-01-26 Initial commit of KiCad projects for new hardware design
    [Audio.kicad_sch, BM62 Daughterboard.kicad_pcb, BM62 Daughterboard.kicad_sch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]
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2024-01-27 Remove unnecessary interrupt disable/enable code when putting the MCU to sleep
    Disabling interrupts was only necessary before I added code to disable all peripherals I didn't want operating during sleep.
2024-01-27 Increase battery voltage divider resistor values to reduce power consumption when powered off
    Increased value of battery voltage divider resistors by about 10x to reduce current draw from about 1.4 mA to about 0.13 mA. This reduces a major source of current draw when the phone is "off" and th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
    Increased ADC acquisition time to account for higher impedance input (about 90k, compared to datasheet recommended max of 10k).
    Added a 10nF capacitor to the ADC input pin as a "reservoir" to help charge the sample/hold cap despite the high impedance.
    Adjusted min/max battery level ADC value mappings to account for change in voltage divider ratio.
    [Power Supply.kicad_sch]
2024-01-28 Align some components better on the BM62 Daughterboard PCB
    [BM62 Daughterboard.kicad_pcb]
2024-01-28 Update LED part info for BM62 Daughterboard
    [BM62 Daughterboard.kicad_pcb, BM62 Daughterboard.kicad_sch]
2024-01-30 Update battery voltage divider to use larger resistor values
    Increase voltage divider resistor values to reduce current draw. Since I am never switching ADC input pins on the MCU and sampling rate is very low (once per 5 seconds), the very high impedance does 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
    Also updated JLCPCB part numbers for several resistors and capacitors to use "basic" parts instead of "extended" parts.
    [Audio.kicad_sch, M92 Bluetooth Adapter Motherboard.kicad_sch, Power Supply.kicad_sch]
2024-02-01 Update pairing to use 4-digit PIN
    When pairing the Bluetooth to a cell phone, a 4-digit PIN is now displayed on the car phone handset that must be entered on the cell phone that it is pairing to.
    Entering pairing mode on the car phone now erases memory of the currently paired cell phone.
    Removed the PIN-protected ability to erase memory of the currently paired cell phone when viewing the paired cell phone Bluetooth name (simply enter and exit pairing mode if you want to clear this out).
    Also changed format of BM62 configuration to be a "UI Patch" instead of a "Full EEPROM" to avoid overwriting the BM62's unique Bluetooth Address (BD_ADDR) with a default address.
    [bt_command_send.c]
2024-02-05 Create new symbol/footprint for original 8-pin header on transceiver PCB
    [M92 Bluetooth Adapter Motherboard.kicad_sch]
2024-02-05 Temporarily hard-code detected battery level to 100%
    I fried the analog input pin with 12V so it's always reading an ADC value of zero and preventing the phone from turning on. This is a temporary hack until I get a new MCU.
    [battery.c]
2024-02-09 Another attempt to fix strange mic audio issues caused by disabling AEC
    The BM62 doesn't seem to like handling commands to enable/disable AEC too soon after entering a state where the microphone is used (SCO connected and in a call or in voice command).
    A delay of 1 second seems to make it reliable. Afterward, no delay is needed when switching between handset and hands-free mic. But more testing is needed.
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2024-02-09 Adjust power on/off sequence timings
    * Reduced duration of PWR button holds needed to power on/off to be similar to original phone.
    * Removed all explicit resetting of handset state before power off (was a hack to reduce current draw of handset before switching relay off, reducing chance of arcing/sticking; no longer needed due to solid state load switch).
    * Adjusted delay between PWR button release and power off to match original phone.
    * Adjusted delay between handset power on and LCD angle adjust to match original phone.
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2024-02-10 Update circuit/PCB to use different power supply/switching components
    * Use more efficient 5V regulator.
    * Use load switch ICs instead of reed switch relays for power switching.
    * Swapped MCU pins for battery voltage detect and power switching for better PCB layout.
    [M92 Bluetooth Adapter Motherboard.kicad_sch, Power Supply.kicad_sch]
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2024-02-23 Motherboard circuit/PCB adjustments
    * Add 100uf cap to stabilize the 5V power supply (reduce voltage dip during power-on of switched 5V supply).
    * Add cap to 12V load switch to reduce inrush current when powering on handset.
    * Part number updates to more readily available parts.
    [Audio.kicad_sch, M92 Bluetooth Adapter Motherboard.kicad_sch, Power Supply.kicad_sch]
2024-02-23 BM62 daughterboard adjustment to connector ground pins
    [BM62 Daughterboard.kicad_pcb, BM62 Daughterboard.kicad_sch]
2024-02-24 Keep handset powered on during restarts
    Inverted the switched power enable signal from the MCU with a transistor so that switched power is on by default unless the MCU explicitly disables it. This allows everything to remain powered on while the MCU reboots for a restart. If the MCU is rebooting to power off, then it immediately turns switched power off before entering the sleep state.
    This is simpler and more robust than attempting to write code to fully reinitialize ALL MCU state/memory except for switched power enable output.
    [M92 Bluetooth Adapter Motherboard.kicad_sch, Power Supply.kicad_sch]
2024-02-25 Simplify load switch enable circuit, and add 100uF cap to 12V supply
    Eliminated the load switch enable inverting transistor and simplified to a combination of a pull-up resistor on the enable pin with open-drain and initially high configuration of the MCU pin.
    This still keeps the load switches enabled during a MCU reboot like the previous design, but with fewer components and less wasted power.
    Also added a 100uF capacitor to the 12V supply to help reduce voltage dips.
    [M92 Bluetooth Adapter Motherboard.kicad_sch, Power Supply.kicad_sch]
2024-03-01 Minor circuit and PCB layout adjustments
    * Enable quick output discharge feature of both load switches.
    * Change a decoupling cap from 1uF to 0.1uF for consistency.
    * Fix incorrect labeling on the PCB of the BT module connector pinout.
    [Audio.kicad_sch, Power Supply.kicad_sch]
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2024-03-14 Minor schematic/pcb fixes
    [Audio.kicad_sch, M92 Bluetooth Adapter Motherboard.kicad_sch, Power Supply.kicad_sch]
2024-03-14 Fix power-off sound to use high tone instead of low tone
2024-03-17 Delete unused KiCad projects
    I decided to reuse original connectors from the car phone instead of trying to fabricate something vaguely equivalent.
    [Header 4x2 Mount.kicad_pcb, Header 4x2 Mount.kicad_sch, Socket 4x2 Riser.kicad_pcb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]
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2024-04-25 BM62 Daughterboard fixes
    * Fixed some pin assignments that I must have messed up previously
    * Added JLCPCB part numbers for parts on the bottom side
    [BM62 Daughterboard.kicad_pcb, BM62 Daughterboard.kicad_sch]
2024-04-25 Add a datasheet to motherboard schematic
    [Power Supply.kicad_sch]
2024-12-31 Rework load switch enable circuitry/code
    Rework load switch enable circuitry/code to fix brief power-on glitch when initially connecting battery power.
    [Audio.kicad_sch, M92 Bluetooth Adapter Motherboard.kicad_sch, Power Supply.kicad_sch]
2024-12-31 Minor BM62 daughterboard PCB improvements
    * Center/align some components.
    * Setup proper copper exclusion in the BM62 footprint.
    * Increase width of several ground connections.
    [BM62 Daughterboard.kicad_pcb]
2024-12-31 Clean up BM62 Daughterboard KiCad project
    * Use generalized names for project-level symbol/footprint/model libraries.
    * Remove a 3D model that belongs in the SymacSys_Parts library.
    [BM62 Daughterboard.kicad_pcb, BM62 Daughterboard.kicad_sch]
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2025-01-15 Introduce programming port PCB design
    [Programming Port.kicad_pcb, Programming Port.kicad_sch]
2025-01-15 Partial motherboard PCB updates for test fitting
    This is a partial update to the motherboard PCB layout just so I can get some prototype boards manufactured and test fit with some updated/relocated components before committing to laying out the new custom battery/power management circuitry.
    * Removed representation of Dayton Audio battery module PCB (will be replaced by custom battery circuitry in future).
    * Relocated battery holders, and updated their footprints for sturdier part.
    * Added pin headers for mounting the new programming port PCB.
    * Adjusted positions of several mounting holes in attempt to match reality better (based on actual fitment of the PCB).
    * Adjusted position of BT mod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
    [M92 Bluetooth Adapter Motherboard.kicad_sch, Power Supply.kicad_sch]
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2025-01-17 Add MCU power-on condition console logging
    When the MCU powers on, log the power-on conditions. Also some minor cleanup documentation fixes.
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2025-01-18 Rework handset disconnect detection to fix bugs
    Initial handset disconnect detection was too simple/naive:
    * Sending the PING command with the "send immediately" function could corrupt multi-byte positioned printing commands.
    * Handset can get bogged down by handling many other commands and cause substantial delays in PING response, or sometimes even fail to process the PING at all (RX buffer overflow on the handset?)
    Solution includes:
    * Sending the PING command normally (it will be added to the TX buffer).
    * Adding support for a callback that indicates when bytes are ACTUALLY sent over UART, used to detect when the PING command is actually sent, triggering the start of the PING timeout.
    *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
2025-02-19 Add new battery module to motherboard schematic
    [Audio.kicad_sch, Battery Charger.kicad_sch, Battery Module.kicad_sch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]
